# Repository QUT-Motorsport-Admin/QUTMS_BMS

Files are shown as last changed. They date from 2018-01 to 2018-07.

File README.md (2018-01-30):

QUTMS_Banner

# QUT Motorsport - Battery Management

### What
What is the system
### Why
Why is it there, whats its main purpose
### How
How dose it work, interact with other systems, whats its responding too, whats its enacting on
### Where
Where dose it sit in the grand scheme of things, whats its heirachy, where is it physicaly in the car
### Who
Who are the people that have worked on it over time

## Specific README's
These will cover any specific features, outlines or documentation that a programmer/designer should know about. Any specifics, or this outside the overview/outline please update an entry in the wiki

[Hardware](https://github.com/Technosasquach/QUTMS_BMS/tree/master/hardware "Hardware")

[Software](https://github.com/Technosasquach/QUTMS_BMS/tree/master/software "Software")

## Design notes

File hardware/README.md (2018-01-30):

# Battery Management System Hardware

Please update this as important hardware information comes to light

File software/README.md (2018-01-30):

# Battery Management System Software

The software for this project is in two parts. The controller system, and the accumulator system.

## AMU - Accumulator

A rough outline of the software process

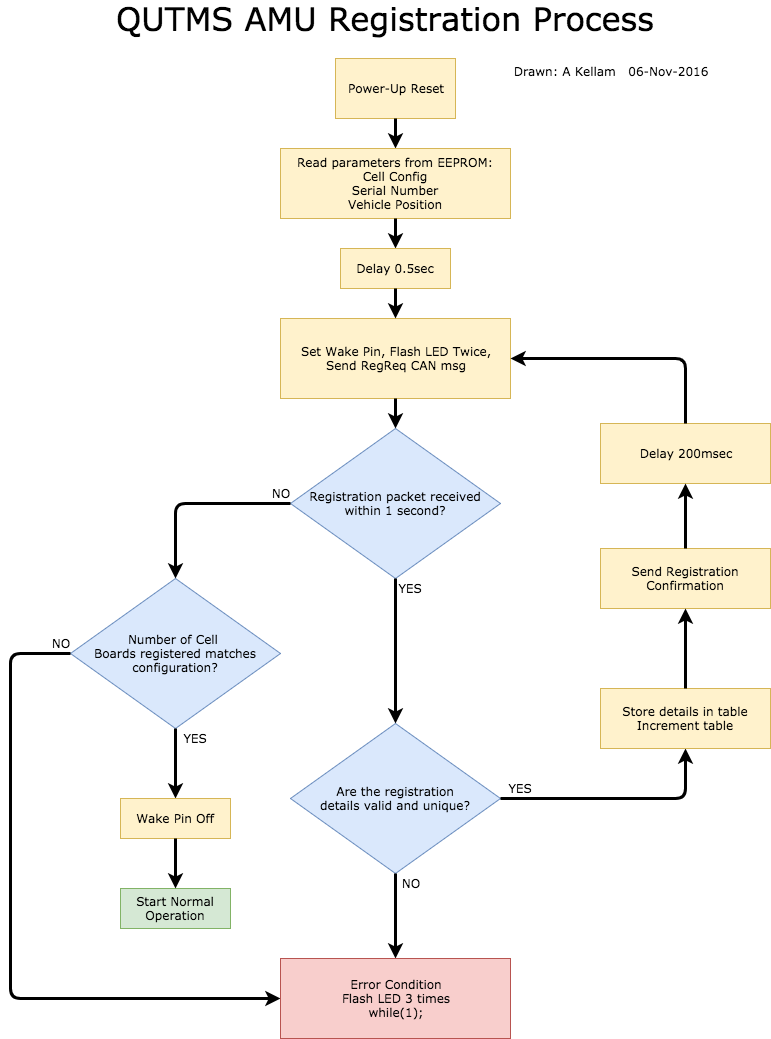
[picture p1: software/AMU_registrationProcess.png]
AccumulatorStartUpProcess


## CMU - Controller

A rough outline of the software process

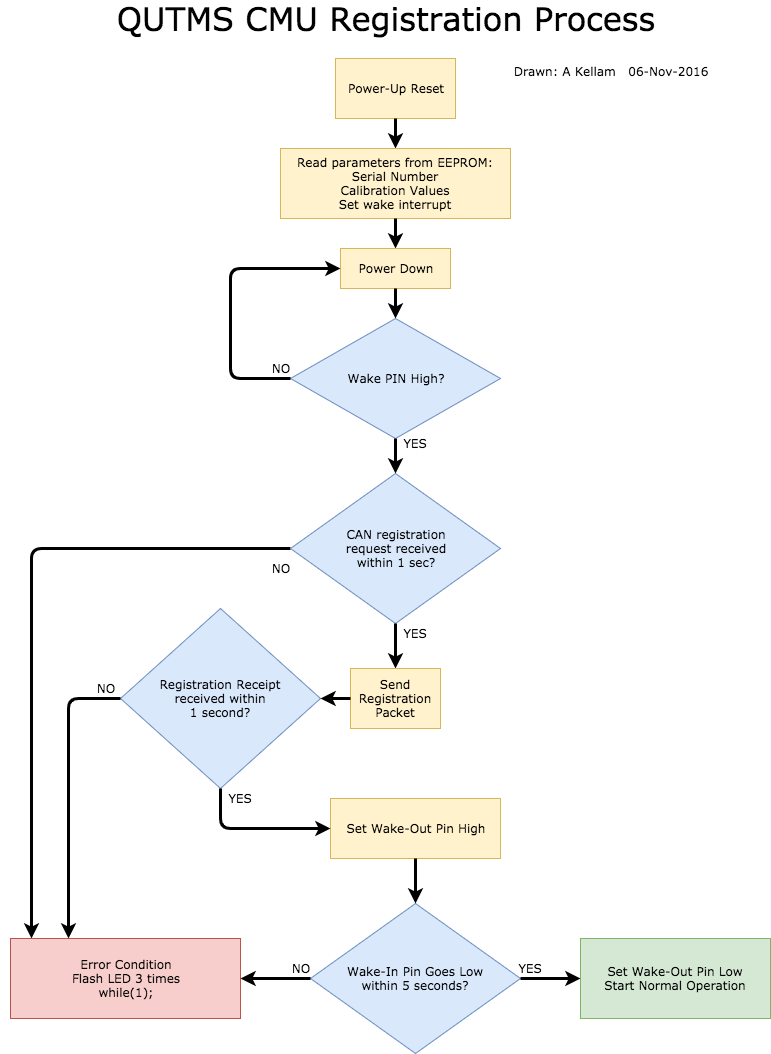
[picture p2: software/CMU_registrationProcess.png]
ControllerStartUpProcess


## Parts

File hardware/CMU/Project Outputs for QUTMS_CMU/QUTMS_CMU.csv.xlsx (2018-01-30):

Comment | Description | Designator | Footprint | LibRef | Supplier 1 | Pricing 1 | Pricing 2 | Quantity
100pF | 603 | C1, C2, C3, C4, C5, C6, C7, C8 | 1608[0603] | Cap Semi | Digi-Key | 1=0.14, 10=0.043, 25=0.0304, 50=0.0236, 100=0.0198, 500=0.01386, 1000=0.01079 (AUD) |  | 8
18pF | 603 | C9, C10 | 1608[0603] | Cap Semi |  |  |  | 2
1uF | 603 | C11, C38, C99 | 1608[0603] | Cap Semi |  |  |  | 3
100nF | 603 | C12, C14, C16, C17, C21, C22, C39, C40, C41, C50, C52 | 1608[0603] | Cap Semi | Digi-Key | 1=0.14, 10=0.028, 25=0.02, 50=0.0152, 100=0.0123, 250=0.01036, 500=0.00882, 1000=0.00693 (AUD) |  | 11
4.7uF | 603 | C13 | 1608[0603] | Cap Semi |  |  |  | 1
603 | 1uF, 47nF | C15, C20 | 1608[0603] | Cap Semi |  |  |  | 2
LED2 | Typical RED, GREEN, YELLOW, AMBER GaAs LED | D1 | 2012[0805]_Res | LED2 | Digi-Key | 1=0.54, 10=0.39, 25=0.2876, 100=0.2054, 250=0.13972, 500=0.12324, 1000=0.09655 (AUD) |  | 1
PWR | Typical RED, GREEN, YELLOW, AMBER GaAs LED | D2 | 2012[0805]_Res | LED2 | Digi-Key | 1=0.37, 10=0.274, 25=0.202, 100=0.1444, 250=0.09816, 500=0.08662, 1000=0.06785 (AUD) |  | 1
Fuse 1 | Fuse | F1, F2, F3, F4, F5, F6, F7, F8 | 3216[1206] | Fuse 1 | Digi-Key | 1=0.79, 50=0.5616, 100=0.5303, 250=0.49916, 500=0.46796 (AUD) |  | 8
Fuse 1 | Fuse | F9, F10, F11, F12, F13, F14, F15, F16 | 6426[2410]_Fuse | Fuse 1 | Digi-Key | 1=0.49, 10=0.458, 25=0.4224, 100=0.3796, 250=0.33808, 500=0.28172, 1000=0.26696, 2500=0.23879 (AUD) |  | 8
ISP header | Header, 3-Pin, Dual row | J1 | ISP Header | Header 3X2 | Digi-Key | 1=1.46, 10=1.283, 25=1.208, 50=1.1578, 100=1.1073 (AUD) |  | 1
Molex Connector | Header, 3-Pin, Dual row | J2 | MOLEX_6H_2 | Header 3X2A | Digi-Key | 1=4.47, 10=4.292, 25=3.934, 50=3.7552, 100=3.5761 (AUD) |  | 1
Molex Connector | Header, 3-Pin, Dual row | J3 | MOLEX_6H_1 | Header 3X2A | Digi-Key | 1=4.47, 10=4.292, 25=3.934, 50=3.7552, 100=3.5761 (AUD) |  | 1
10uH | 805 | L1 | 2012[0805]_IND | Inductor |  |  |  | 1
MOSFET-N | N-Channel MOSFET | Q1, Q2, Q3, Q4, Q5, Q6, Q7, Q8 | D2PAK_L | MOSFET-N | Digi-Key | 1=2.1, 10=1.888, 100=1.5146, 500=1.24488, 1000=1.03048 (AUD) | 1=0.8, 10=0.686, 100=0.5121, 500=0.4022, 1000=0.31009 (AUD) | 8
2N7002 | N-Channel MOSFET | Q9 | SOT23_N | MOSFET-N | Digi-Key | 1=0.19, 10=0.177, 100=0.0968, 500=0.05954, 1000=0.04061 (AUD) |  | 1
MOSFET-P | P-Channel MOSFET | Q10 | SOT23_N | MOSFET-P | Digi-Key | 1=0.5, 10=0.401, 25=0.3672, 100=0.2736, 250=0.24792, 500=0.20516, 1000=0.15387 (AUD) |  | 1
4R7 | Power Resistor SMD | R1, R2, R3, R4, R5, R6, R7, R8 | D2PAK_N | Res1 | Digi-Key | 1=3.71, 10=3.283, 25=3.0432, 50=2.8642, 100=2.5061, 250=2.14812, 500=1.7901, 1000=1.55142, 2500=1.52159 (AUD) |  | 8
1k | 805 | R9, R10, R11, R12, R13, R14, R15, R16, R60, R61, R63, R64, R65, R66, R69 | 2012[0805]_Res | Res1 |  |  |  | 15
560k | 805 | R17, R18, R19, R20, R21, R22, R23, R24, R25, R26, R27, R28, R29, R30, R31, R33, R34, R35, R36, R37, R38, R39, R40, R42, R43, R44, R45, R46, R47, R48 | 2012[0805]_Res | Res1 | Digi-Key | 1=0.14, 10=0.024, 25=0.0172, 100=0.0099, 250=0.00752, 500=0.006, 1000=0.00441, 2500=0.00383 (AUD) | 1=0.88, 50=0.3502, 100=0.2701, 250=0.21008, 500=0.14806, 1000=0.10804 (AUD) | 30
47k | 805 | R32, R41, R49, R50, R58, R59, R62, R83, R84, R85, R88, R97 | 2012[0805]_Res | Res1, Res1, Res1, Res1, Res1, Res1, Res1, Res1, Res1, Res1, Res3, Res1 | Digi-Key | 1=0.14, 50=0.021, 100=0.0154, 250=0.0118, 500=0.00946, 1000=0.00696 (AUD) |  | 12
10k | 805 | R51, R52, R53, R54, R55, R56, R57, R79, R80, R81, R82, R95a, R95b, R98 | 2012[0805]_Res | Res1 | Digi-Key | 1=0.14, 50=0.021, 100=0.0154, 250=0.0118, 500=0.00946, 1000=0.00696 (AUD) |  | 14
4k7 | 805 | R68, R70, R71, R72, R73, R74, R75, R76, R77 | 2012[0805]_Res | Res1, Res3, Res3, Res3, Res3, Res3, Res3, Res3, Res3 |  |  |  | 9
330R | 805 | R78 | 2012[0805]_Res | Res1 |  |  |  | 1
805 | 1k | R89 | 2012[0805]_Res | Res1 |  |  |  | 1
270R | 805 | R90, R91 | 2012[0805]_Res | Res1 |  |  |  | 2
22k | 805 | R96 | 2012[0805]_Res | Res1 |  |  |  | 1
10R | 805 | R99 | 2012[0805]_Res | Res1 |  |  |  | 1
Res Thermal | Thermistor | TH1, TH2, TH3, TH4, TH5, TH6, TH7, TH8 | HDR1X2 | Res Thermal |  |  |  | 8
ATmega64M1-16AU | 8-Bit AVR Microcontroller with 8K Bytes of In-System Programmable Flash Memory | U1 | 32A_N | ATmega8-16AC |  |  |  | 1
ISO1050 | Isolated CAN transceiver | U5 | DUB8 | AT90S2343-10SI | Digi-Key | 1=6.31, 10=5.665, 100=4.647 (AUD) |  | 1
MC33174D | Low-Power Quad Bipolar Operational Amplifier | U6, U7 | SO14_N | MC33174D | Digi-Key | 1=1.18, 10=1.036, 100=0.7921, 500=0.62762, 1000=0.5027 (AUD) |  | 2
Optoisolator1 | 4-Pin Phototransistor Optocoupler | U10, U11, U14, U15, U16, U17, U18, U19, U21 | SO4 | Optoisolator1 | Digi-Key | 1=1.12, 10=0.864, 25=0.718, 100=0.6172, 250=0.53864, 500=0.4713, 750=0.41521, 1000=0.37031 (AUD) |  | 9
Optoisolator3 | 4-Pin Phototransistor Optocoupler | U12 | SO4 | Optoisolator1 | Digi-Key | 1=1.12, 10=0.864, 25=0.718, 100=0.6172, 250=0.53864, 500=0.4713, 750=0.41521, 1000=0.37031 (AUD) |  | 1
Optoisolator4 | 4-Pin Phototransistor Optocoupler | U13 | SO4 | Optoisolator1 | Digi-Key | 1=1.12, 10=0.864, 25=0.718, 100=0.6172, 250=0.53864, 500=0.4713, 750=0.41521, 1000=0.37031 (AUD) |  | 1
74HC4051 | Wideband Dual-Channel Linear Multiplier/Divider | U20 | SO-16 | AD539KN | Digi-Key | 1=0.63, 10=0.51, 100=0.3475, 500=0.2601, 1000=0.19481 (AUD) |  | 1
5V LDO INH Reg | IC REG LDO 5V 0.4A TO252-5 | VR1 | DPAK-5 | IFX25401TE V50 | Digi-Key | 1=1.48, 10=1.325, 100=1.0328, 500=0.85324, 1000=0.6736 (AUD) |  | 1
MC78M05BDTRK | Three-Terminal Medium Current Positive Voltage Regulator | VR2 | D2PAK | MC78M05BDTRK | Digi-Key | 1=0.62, 10=0.531, 100=0.3968, 500=0.31168, 1000=0.24029 (AUD) |  | 1
16MHz | Crystal Oscillator | Y1 | Crystal | XTAL | Digi-Key | 1=0.32, 10=0.274, 50=0.2452, 100=0.2182, 500=0.2078 (AUD) |  | 1

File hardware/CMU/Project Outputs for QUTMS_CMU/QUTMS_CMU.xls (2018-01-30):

Comment | Description | Designator | Footprint | LibRef | Supplier 1 | Pricing 1 | Pricing 2 | Quantity
100pF | 0603 | C1, C2, C3, C4, C5, C6, C7, C8 | 1608[0603] | Cap Semi | Digi-Key | 1=0.14, 10=0.043, 25=0.0304, 50=0.0236, 100=0.0198, 500=0.01386, 1000=0.01079 (AUD) |  | 8.0
18pF | 0603 | C9, C10 | 1608[0603] | Cap Semi |  |  |  | 2.0
1uF | 0603 | C11, C38, C99 | 1608[0603] | Cap Semi |  |  |  | 3.0
100nF | 0603 | C12, C14, C16, C17, C21, C22, C39, C40, C41, C50, C52 | 1608[0603] | Cap Semi | Digi-Key | 1=0.14, 10=0.028, 25=0.02, 50=0.0152, 100=0.0123, 250=0.01036, 500=0.00882, 1000=0.00693 (AUD) |  | 11.0
4.7uF | 0603 | C13 | 1608[0603] | Cap Semi |  |  |  | 1.0
0603 | 1uF, 47nF | C15, C20 | 1608[0603] | Cap Semi |  |  |  | 2.0
LED2 | Typical RED, GREEN, YELLOW, AMBER GaAs LED | D1 | 2012[0805]_Res | LED2 | Digi-Key | 1=0.54, 10=0.39, 25=0.2876, 100=0.2054, 250=0.13972, 500=0.12324, 1000=0.09655 (AUD) |  | 1.0
PWR | Typical RED, GREEN, YELLOW, AMBER GaAs LED | D2 | 2012[0805]_Res | LED2 | Digi-Key | 1=0.37, 10=0.274, 25=0.202, 100=0.1444, 250=0.09816, 500=0.08662, 1000=0.06785 (AUD) |  | 1.0
Fuse 1 | Fuse | F1, F2, F3, F4, F5, F6, F7, F8 | 3216[1206] | Fuse 1 | Digi-Key | 1=0.79, 50=0.5616, 100=0.5303, 250=0.49916, 500=0.46796 (AUD) |  | 8.0
Fuse 1 | Fuse | F9, F10, F11, F12, F13, F14, F15, F16 | 6426[2410]_Fuse | Fuse 1 | Digi-Key | 1=0.49, 10=0.458, 25=0.4224, 100=0.3796, 250=0.33808, 500=0.28172, 1000=0.26696, 2500=0.23879 (AUD) |  | 8.0
ISP header | Header, 3-Pin, Dual row | J1 | ISP Header | Header 3X2 | Digi-Key | 1=1.46, 10=1.283, 25=1.208, 50=1.1578, 100=1.1073 (AUD) |  | 1.0
Molex Connector | Header, 3-Pin, Dual row | J2 | MOLEX_6H_2 | Header 3X2A | Digi-Key | 1=4.47, 10=4.292, 25=3.934, 50=3.7552, 100=3.5761 (AUD) |  | 1.0
Molex Connector | Header, 3-Pin, Dual row | J3 | MOLEX_6H_1 | Header 3X2A | Digi-Key | 1=4.47, 10=4.292, 25=3.934, 50=3.7552, 100=3.5761 (AUD) |  | 1.0
10uH | 0805 | L1 | 2012[0805]_IND | Inductor |  |  |  | 1.0
MOSFET-N | N-Channel MOSFET | Q1, Q2, Q3, Q4, Q5, Q6, Q7, Q8 | D2PAK_L | MOSFET-N | Digi-Key | 1=2.1, 10=1.888, 100=1.5146, 500=1.24488, 1000=1.03048 (AUD) | 1=0.8, 10=0.686, 100=0.5121, 500=0.4022, 1000=0.31009 (AUD) | 8.0
2N7002 | N-Channel MOSFET | Q9 | SOT23_N | MOSFET-N | Digi-Key | 1=0.19, 10=0.177, 100=0.0968, 500=0.05954, 1000=0.04061 (AUD) |  | 1.0
MOSFET-P | P-Channel MOSFET | Q10 | SOT23_N | MOSFET-P | Digi-Key | 1=0.5, 10=0.401, 25=0.3672, 100=0.2736, 250=0.24792, 500=0.20516, 1000=0.15387 (AUD) |  | 1.0
4R7 | Power Resistor SMD | R1, R2, R3, R4, R5, R6, R7, R8 | D2PAK_N | Res1 | Digi-Key | 1=3.71, 10=3.283, 25=3.0432, 50=2.8642, 100=2.5061, 250=2.14812, 500=1.7901, 1000=1.55142, 2500=1.52159 (AUD) |  | 8.0
1k | 0805 | R9, R10, R11, R12, R13, R14, R15, R16, R60, R61, R63, R64, R65, R66, R69 | 2012[0805]_Res | Res1 |  |  |  | 15.0
560k | 0805 | R17, R18, R19, R20, R21, R22, R23, R24, R25, R26, R27, R28, R29, R30, R31, R33, R34, R35, R36, R37, R38, R39, R40, R42, R43, R44, R45, R46, R47, R48 | 2012[0805]_Res | Res1 | Digi-Key | 1=0.14, 10=0.024, 25=0.0172, 100=0.0099, 250=0.00752, 500=0.006, 1000=0.00441, 2500=0.00383 (AUD) | 1=0.88, 50=0.3502, 100=0.2701, 250=0.21008, 500=0.14806, 1000=0.10804 (AUD) | 30.0
47k | 0805 | R32, R41, R49, R50, R58, R59, R62, R83, R84, R85, R88, R97 | 2012[0805]_Res | Res1, Res1, Res1, Res1, Res1, Res1, Res1, Res1, Res1, Res1, Res3, Res1 | Digi-Key | 1=0.14, 50=0.021, 100=0.0154, 250=0.0118, 500=0.00946, 1000=0.00696 (AUD) |  | 12.0
10k | 0805 | R51, R52, R53, R54, R55, R56, R57, R79, R80, R81, R82, R95a, R95b, R98 | 2012[0805]_Res | Res1 | Digi-Key | 1=0.14, 50=0.021, 100=0.0154, 250=0.0118, 500=0.00946, 1000=0.00696 (AUD) |  | 14.0
4k7 | 0805 | R68, R70, R71, R72, R73, R74, R75, R76, R77 | 2012[0805]_Res | Res1, Res3, Res3, Res3, Res3, Res3, Res3, Res3, Res3 |  |  |  | 9.0
330R | 0805 | R78 | 2012[0805]_Res | Res1 |  |  |  | 1.0
0805 | 1k | R89 | 2012[0805]_Res | Res1 |  |  |  | 1.0
270R | 0805 | R90, R91 | 2012[0805]_Res | Res1 |  |  |  | 2.0
22k | 0805 | R96 | 2012[0805]_Res | Res1 |  |  |  | 1.0
10R | 0805 | R99 | 2012[0805]_Res | Res1 |  |  |  | 1.0
Res Thermal | Thermistor | TH1, TH2, TH3, TH4, TH5, TH6, TH7, TH8 | HDR1X2 | Res Thermal |  |  |  | 8.0
ATmega64M1-16AU | 8-Bit AVR Microcontroller with 8K Bytes of In-System Programmable Flash Memory | U1 | 32A_N | ATmega8-16AC |  |  |  | 1.0
ISO1050 | Isolated CAN transceiver | U5 | DUB8 | AT90S2343-10SI | Digi-Key | 1=6.31, 10=5.665, 100=4.647 (AUD) |  | 1.0
MC33174D | Low-Power Quad Bipolar Operational Amplifier | U6, U7 | SO14_N | MC33174D | Digi-Key | 1=1.18, 10=1.036, 100=0.7921, 500=0.62762, 1000=0.5027 (AUD) |  | 2.0
Optoisolator1 | 4-Pin Phototransistor Optocoupler | U10, U11, U14, U15, U16, U17, U18, U19, U21 | SO4 | Optoisolator1 | Digi-Key | 1=1.12, 10=0.864, 25=0.718, 100=0.6172, 250=0.53864, 500=0.4713, 750=0.41521, 1000=0.37031 (AUD) |  | 9.0
Optoisolator3 | 4-Pin Phototransistor Optocoupler | U12 | SO4 | Optoisolator1 | Digi-Key | 1=1.12, 10=0.864, 25=0.718, 100=0.6172, 250=0.53864, 500=0.4713, 750=0.41521, 1000=0.37031 (AUD) |  | 1.0
Optoisolator4 | 4-Pin Phototransistor Optocoupler | U13 | SO4 | Optoisolator1 | Digi-Key | 1=1.12, 10=0.864, 25=0.718, 100=0.6172, 250=0.53864, 500=0.4713, 750=0.41521, 1000=0.37031 (AUD) |  | 1.0
74HC4051 | Wideband Dual-Channel Linear Multiplier/Divider | U20 | SO-16 | AD539KN | Digi-Key | 1=0.63, 10=0.51, 100=0.3475, 500=0.2601, 1000=0.19481 (AUD) |  | 1.0
5V LDO INH Reg | IC REG LDO 5V 0.4A TO252-5 | VR1 | DPAK-5 | IFX25401TE V50 | Digi-Key | 1=1.48, 10=1.325, 100=1.0328, 500=0.85324, 1000=0.6736 (AUD) |  | 1.0
MC78M05BDTRK | Three-Terminal Medium Current Positive Voltage Regulator | VR2 | D2PAK | MC78M05BDTRK | Digi-Key | 1=0.62, 10=0.531, 100=0.3968, 500=0.31168, 1000=0.24029 (AUD) |  | 1.0
16MHz | Crystal Oscillator | Y1 | Crystal | XTAL | Digi-Key | 1=0.32, 10=0.274, 50=0.2452, 100=0.2182, 500=0.2078 (AUD) |  | 1.0

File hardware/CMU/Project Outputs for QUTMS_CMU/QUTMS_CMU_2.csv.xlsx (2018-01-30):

Comment | Description | Designator | Footprint | LibRef | Supplier 1 | Pricing 1 | Pricing 2 | Quantity | Manufacturer | Manufacturer Part Number | ComponentLink1URL | ComponentLink2URL | ComponentLink3URL
100pF | 603 | C1, C2, C3, C4, C5, C6, C7, C8 | 1608[0603] | Cap Semi | Digi-Key | 1=0.14, 10=0.043, 25=0.0304, 50=0.0236, 100=0.0198, 500=0.01386, 1000=0.01079 (AUD) |  | 8 | Samsung Electro-Mechanics America, Inc. | CL10B101KB8NNNC | http://www.samsungsem.com/kr/support/product-search/mlcc/CL10B101KB8NNNC.jsp
18pF | 603 | C9, C10 | 1608[0603] | Cap Semi |  |  |  | 2
1uF | 603 | C11, C38, C99 | 1608[0603] | Cap Semi |  |  |  | 3
100nF | 603 | C12, C14, C16, C17, C21, C22, C39, C40, C41, C50, C52 | 1608[0603] | Cap Semi | Digi-Key | 1=0.14, 10=0.028, 25=0.02, 50=0.0152, 100=0.0123, 250=0.01036, 500=0.00882, 1000=0.00693 (AUD) |  | 11 | Samsung Electro-Mechanics America, Inc. | CL10B104KB8SFNC | http://www.samsungsem.com/kr/support/product-search/mlcc/CL10B104KB8SFNC.jsp
4.7uF | 603 | C13 | 1608[0603] | Cap Semi |  |  |  | 1
603 | 1uF, 47nF | C15, C20 | 1608[0603] | Cap Semi |  |  |  | 2
LED2 | Typical RED, GREEN, YELLOW, AMBER GaAs LED | D1 | 2012[0805]_Res | LED2 | Digi-Key | 1=0.54, 10=0.39, 25=0.2876, 100=0.2054, 250=0.13972, 500=0.12324, 1000=0.09655 (AUD) |  | 1 | Kingbright | APT2012SGC | http://www.kingbrightusa.com/images/catalog/SPEC/APT2012SGC.pdf
PWR | Typical RED, GREEN, YELLOW, AMBER GaAs LED | D2 | 2012[0805]_Res | LED2 | Digi-Key | 1=0.37, 10=0.274, 25=0.202, 100=0.1444, 250=0.09816, 500=0.08662, 1000=0.06785 (AUD) |  | 1 | OSRAM Opto Semiconductors Inc. | LS R976-NR-1 | http://www.osram-os.com/Graphics/XPic8/00078896_0.pdf
Fuse 1 | Fuse | F1, F2, F3, F4, F5, F6, F7, F8 | 3216[1206] | Fuse 1 | Digi-Key | 1=0.79, 50=0.5616, 100=0.5303, 250=0.49916, 500=0.46796 (AUD) |  | 8 | Schurter Inc. | 3413.0008.22 | http://www.schurterinc.com/bundles/snceschurter/epim/_ProdPool_/newDS/en/typ_USFF_1206.pdf
Fuse 1 | Fuse | F9, F10, F11, F12, F13, F14, F15, F16 | 6426[2410]_Fuse | Fuse 1 | Digi-Key | 1=0.49, 10=0.458, 25=0.4224, 100=0.3796, 250=0.33808, 500=0.28172, 1000=0.26696, 2500=0.23879 (AUD) |  | 8 | Bel Fuse Inc. | 0679L5000-05 | http://belfuse.com/pdfs/0679L.pdf
ISP header | Header, 3-Pin, Dual row | J1 | ISP Header | Header 3X2 | Digi-Key | 1=1.46, 10=1.283, 25=1.208, 50=1.1578, 100=1.1073 (AUD) |  | 1 | Amphenol FCI | 95278-101A06LF | http://portal.fciconnect.com/Comergent//fci/drawing/95278.pdf
Molex Connector | Header, 3-Pin, Dual row | J2 | MOLEX_6H_2 | Header 3X2A | Digi-Key | 1=4.47, 10=4.292, 25=3.934, 50=3.7552, 100=3.5761 (AUD) |  | 1 | Molex, LLC | 430450610 | http://www.molex.com/pdm_docs/sd/430450610_sd.pdf
Molex Connector | Header, 3-Pin, Dual row | J3 | MOLEX_6H_1 | Header 3X2A | Digi-Key | 1=4.47, 10=4.292, 25=3.934, 50=3.7552, 100=3.5761 (AUD) |  | 1 | Molex, LLC | 430450610 | http://www.molex.com/pdm_docs/sd/430450610_sd.pdf
10uH | 805 | L1 | 2012[0805]_IND | Inductor |  |  |  | 1
MOSFET-N | N-Channel MOSFET | Q1, Q2, Q3, Q4, Q5, Q6, Q7, Q8 | D2PAK_L | MOSFET-N | Digi-Key | 1=2.1, 10=1.888, 100=1.5146, 500=1.24488, 1000=1.03048 (AUD) | 1=0.8, 10=0.686, 100=0.5121, 500=0.4022, 1000=0.31009 (AUD) | 8 | Fairchild Semiconductor | FDD86250 | http://www.fairchildsemi.com/datasheets/FD/FDD86250.pdf | http://www.onsemi.com/pub_link/Collateral/MJD122-D.PDF
2N7002 | N-Channel MOSFET | Q9 | SOT23_N | MOSFET-N | Digi-Key | 1=0.19, 10=0.177, 100=0.0968, 500=0.05954, 1000=0.04061 (AUD) |  | 1 | NXP Semiconductors | 2N7002P,215 | http://www.nxp.com/documents/data_sheet/2N7002P.pdf
MOSFET-P | P-Channel MOSFET | Q10 | SOT23_N | MOSFET-P | Digi-Key | 1=0.5, 10=0.401, 25=0.3672, 100=0.2736, 250=0.24792, 500=0.20516, 1000=0.15387 (AUD) |  | 1 | Vishay Siliconix | TP0610K-T1-GE3 | http://www.vishay.com/docs/71411/tp0610k.pdf
4R7 | Power Resistor SMD | R1, R2, R3, R4, R5, R6, R7, R8 | D2PAK_N | Res1 | Digi-Key | 1=3.71, 10=3.283, 25=3.0432, 50=2.8642, 100=2.5061, 250=2.14812, 500=1.7901, 1000=1.55142, 2500=1.52159 (AUD) | 1=3.65, 10=3.234, 25=2.9984, 50=2.8218, 100=2.469, 250=2.11628, 500=1.76358, 1000=1.52844, 2500=1.49904 (AUD) | 8 | Bourns Inc. | PWR163S-25-1R00J | http://www.bourns.com/docs/Product-Datasheets/PWR163.pdf
1k | 805 | R9, R10, R11, R12, R13, R14, R15, R16, R60, R61, R63, R64, R65, R66, R69 | 2012[0805]_Res | Res1 |  |  |  | 15
560k | 805 | R17, R18, R19, R20, R21, R22, R23, R24, R25, R26, R27, R28, R29, R30, R31, R33, R34, R35, R36, R37, R38, R39, R40, R42, R43, R44, R45, R46, R47, R48 | 2012[0805]_Res | Res1 | Digi-Key | 1=0.14, 10=0.024, 25=0.0172, 100=0.0099, 250=0.00752, 500=0.006, 1000=0.00441, 2500=0.00383 (AUD) | 1=0.88, 50=0.3502, 100=0.2701, 250=0.21008, 500=0.14806, 1000=0.10804 (AUD) | 30 | Yageo | RC0805JR-07560KL | http://www.yageo.com/documents/recent/PYu-RC_Group_51_RoHS_L_04.pdf | http://media.digikey.com/pdf/Data%20Sheets/Panasonic%20Electronic%20Components/ERA%201A,2A,3A,6A,8A.pdf
47k | 805 | R32, R41, R49, R50, R58, R59, R62, R83, R84, R85, R88, R97 | 2012[0805]_Res | Res1, Res1, Res1, Res1, Res1, Res1, Res1, Res1, Res1, Res1, Res3, Res1 | Digi-Key | 1=0.14, 50=0.021, 100=0.0154, 250=0.0118, 500=0.00946, 1000=0.00696 (AUD) |  | 12 | Panasonic Electronic Components | ERJ-6GEYJ473V | http://industrial.panasonic.com/www-cgi/jvcr13pz.cgi?E+PZ+3+AOA0001+ERJ6GEYJ473V+7+WW
10k | 805 | R51, R52, R53, R54, R55, R56, R57, R79, R80, R81, R82, R95a, R95b, R98 | 2012[0805]_Res | Res1 | Digi-Key | 1=0.14, 50=0.021, 100=0.0154, 250=0.0118, 500=0.00946, 1000=0.00696 (AUD) |  | 14 | Panasonic Electronic Components | ERJ-6GEYJ103V | http://industrial.panasonic.com/www-cgi/jvcr13pz.cgi?E+PZ+3+AOA0001+ERJ6GEYJ103V+7+WW
4k7 | 805 | R68, R70, R71, R72, R73, R74, R75, R76, R77 | 2012[0805]_Res | Res1, Res3, Res3, Res3, Res3, Res3, Res3, Res3, Res3 |  |  |  | 9
330R | 805 | R78 | 2012[0805]_Res | Res1 |  |  |  | 1
805 | 1k | R89 | 2012[0805]_Res | Res1 |  |  |  | 1
270R | 805 | R90, R91 | 2012[0805]_Res | Res1 |  |  |  | 2
22k | 805 | R96 | 2012[0805]_Res | Res1 |  |  |  | 1
10R | 805 | R99 | 2012[0805]_Res | Res1 |  |  |  | 1
Res Thermal | Thermistor | TH1, TH2, TH3, TH4, TH5, TH6, TH7, TH8 | HDR1X2 | Res Thermal |  |  |  | 8
ATmega64M1-16AU | 8-Bit AVR Microcontroller with 8K Bytes of In-System Programmable Flash Memory | U1 | 32A_N | ATmega8-16AC |  |  |  | 1 |  |  | http://www.atmel.com | http://www.atmel.com/dyn/resources/prod_documents/doc2486.pdf
ISO1050 | Isolated CAN transceiver | U5 | DUB8 | AT90S2343-10SI | Digi-Key | 1=6.31, 10=5.665, 100=4.647 (AUD) |  | 1 | Texas Instruments | ISO1050DUBR | http://www.atmel.com | http://www.atmel.com/dyn/resources/prod_documents/doc1004.pdf | http://www.ti.com/lit/ds/symlink/iso1050.pdf
MC33174D | Low-Power Quad Bipolar Operational Amplifier | U6, U7 | SO14_N | MC33174D | Digi-Key | 1=1.18, 10=1.036, 100=0.7921, 500=0.62762, 1000=0.5027 (AUD) |  | 2 | STMicroelectronics | MC33174DT | http://www.st.com/ | http://www.st.com/stonline/products/literature/ds/2180/mc33174.pdf | http://www.st.com/content/ccc/resource/technical/document/datasheet/2e/90/c8/0c/79/aa/43/e1/CD00000477.pdf/files/CD00000477.pdf/jcr:content/translations/en.CD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
Optoisolator1 | 4-Pin Phototransistor Optocoupler | U10, U11, U14, U15, U16, U17, U18, U19, U21 | SO4 | Optoisolator1 | Digi-Key | 1=1.12, 10=0.864, 25=0.718, 100=0.6172, 250=0.53864, 500=0.4713, 750=0.41521, 1000=0.37031 (AUD) |  | 9 | Vishay Semiconductor Opto Division | TCMT1600 | http://www.vishay.com/docs/83512/tcmt1600.pdf
Optoisolator3 | 4-Pin Phototransistor Optocoupler | U12 | SO4 | Optoisolator1 | Digi-Key | 1=1.12, 10=0.864, 25=0.718, 100=0.6172, 250=0.53864, 500=0.4713, 750=0.41521, 1000=0.37031 (AUD) |  | 1 | Vishay Semiconductor Opto Division | TCMT1600 | http://www.vishay.com/docs/83512/tcmt1600.pdf
Optoisolator4 | 4-Pin Phototransistor Optocoupler | U13 | SO4 | Optoisolator1 | Digi-Key | 1=1.12, 10=0.864, 25=0.718, 100=0.6172, 250=0.53864, 500=0.4713, 750=0.41521, 1000=0.37031 (AUD) |  | 1 | Vishay Semiconductor Opto Division | TCMT1600 | http://www.vishay.com/docs/83512/tcmt1600.pdf
74HC4051 | Wideband Dual-Channel Linear Multiplier/Divider | U20 | SO-16 | AD539KN | Digi-Key | 1=0.63, 10=0.51, 100=0.3475, 500=0.2601, 1000=0.19481 (AUD) |  | 1 | NXP Semiconductors | 74HC4051D,653 | http://www.analog.com/en/prod/0%2C2877%2CAD539%2C00.html | http://www.analog.com/UploadedFiles/Data_Sheets/533994331AD539_a.pdf | http://www.nxp.com/documents/data_sheet/74HC_HCT4051.pdf
5V LDO INH Reg | IC REG LDO 5V 0.4A TO252-5 | VR1 | DPAK-5 | IFX25401TE V50 | Digi-Key | 1=1.48, 10=1.325, 100=1.0328, 500=0.85324, 1000=0.6736 (AUD) |  | 1 | Infineon Technologies | IFX25401TE V50 | http://www.infineon.com/dgdl/Infineon-IFX25401-DS-v01_02-en.pdf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
MC78M05BDTRK | Three-Terminal Medium Current Positive Voltage Regulator | VR2 | D2PAK | MC78M05BDTRK | Digi-Key | 1=0.62, 10=0.531, 100=0.3968, 500=0.31168, 1000=0.24029 (AUD) |  | 1 | ON Semiconductor | MC78M05CDTRKG | http://www.onsemi.com/site/products/taxonomy/0,4438,503,00.html | http://www.onsemi.com/pub/Collateral/MC78M00-D.PDF | http://www.onsemi.com/pub_link/Collateral/MC78M00-D.PDF
16MHz | Crystal Oscillator | Y1 | Crystal | XTAL | Digi-Key | 1=0.32, 10=0.274, 50=0.2452, 100=0.2182, 500=0.2078 (AUD) |  | 1 | Abracon LLC | ABLS-16.000MHZ-D-4-T | http://www.abracon.com/Resonators/abls.pdf

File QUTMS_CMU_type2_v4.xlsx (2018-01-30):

Comment | Description | Designator | Footprint | LibRef | Quantity
100pF | 0603 | C1, C2, C3, C4, C5, C6, C7, C8 | 1608[0603] | Cap Semi | 8
18pF | 0603 | C9, C10 | 1608[0603] | Cap Semi | 2
1uF | 0603 | C11, C38, C99 | 1608[0603] | Cap Semi | 3
100nF | 0603 | C12, C14, C16, C17, C21, C22, C39, C40, C41, C50, C52 | 1608[0603] | Cap Semi | 11
4.7uF | 0603 | C13 | 1608[0603] | Cap Semi | 1
0603 | 1uF, 47nF | C15, C20 | 1608[0603] | Cap Semi | 2
LED2 | Typical RED, GREEN, YELLOW, AMBER GaAs LED | D1 | 2012[0805]_RES | LED2 | 1
PWR | Typical RED, GREEN, YELLOW, AMBER GaAs LED | D2 | 2012[0805]_RES | LED2 | 1
Fuse 1 | Fuse | F1, F2, F3, F4, F5, F6, F7, F8 | 3216[1206] | Fuse 1 | 8
Fuse 1 | Fuse | F9, F10, F11, F12, F13, F14, F15, F16 | 6426[2410]_Fuse | Fuse 1 | 8
ISP header | Header, 3-Pin, Dual row | J1 | ISP HEADER | Header 3X2 | 1
Molex Connector | Header, 3-Pin, Dual row | J2 | MOLEX_6H_2 | Header 3X2A | 1
Molex Connector | Header, 3-Pin, Dual row | J3 | MOLEX_6H_1 | Header 3X2A | 1
10uH | 0805 | L1 | 2012[0805]_IND | Inductor | 1
 |  | Q1, Q2, Q3, Q4, Q5, Q6, Q7, Q8 | 369A-13 |  | 8
2N7002 | N-Channel MOSFET | Q9 | SOT23_N | MOSFET-N | 1
MOSFET-P | P-Channel MOSFET | Q10 | SOT23_N | MOSFET-P | 1
4R7 | Power Resistor SMD | R1, R2, R3, R4, R5, R6, R7, R8 | D2PAK_N | Res1 | 8
1k | 0805 | R9, R10, R11, R12, R13, R14, R15, R16, R60, R61, R63, R64, R65, R66, R69 | 2012[0805]_RES | Res1 | 15
560k | 0805 | R17, R18, R19, R20, R21, R22, R23, R24, R25, R26, R27, R28, R29, R30, R31, R33, R34, R35, R36, R37, R38, R39, R40, R42, R43, R44, R45, R46, R47, R48 | 2012[0805]_RES | Res1 | 30
47k | 0805 | R32, R41, R49, R50, R58, R59, R62, R83, R84, R85, R88, R97 | 2012[0805]_RES | Res1, Res1, Res1, Res1, Res1, Res1, Res1, Res1, Res1, Res1, Res3, Res1 | 12
10k | 0805 | R51, R52, R53, R54, R55, R56, R57, R79, R80, R81, R82, R95a, R95b, R98 | 2012[0805]_RES | Res1 | 14
4k7 | 0805 | R68, R70, R71, R72, R73, R74, R75, R76, R77 | 2012[0805]_RES | Res1, Res3, Res3, Res3, Res3, Res3, Res3, Res3, Res3 | 9
330R | 0805 | R78 | 2012[0805]_RES | Res1 | 1
0805 | 1k | R89 | 2012[0805]_RES | Res1 | 1
270R | 0805 | R90, R91 | 2012[0805]_RES | Res1 | 2
22k | 0805 | R96 | 2012[0805]_RES | Res1 | 1
10R | 0805 | R99 | 2012[0805]_RES | Res1 | 1
Res Thermal | Thermistor | TH1, TH2, TH3, TH4, TH5, TH6, TH7, TH8 | HDR1X2 | Res Thermal | 8
ATmega64M1-16AU | 8-Bit AVR Microcontroller with 8K Bytes of In-System Programmable Flash Memory | U1 | 32A_N | ATmega8-16AC | 1
ISO1050 | Isolated CAN transceiver | U5 | DUB8 | AT90S2343-10SI | 1
MC33174D | Low-Power Quad Bipolar Operational Amplifier | U6, U7 | SO14_N | MC33174D | 2
Optoisolator1 | 4-Pin Phototransistor Optocoupler | U10, U11, U14, U15, U16, U17, U18, U19, U21 | SO4 | Optoisolator1 | 9
Optoisolator3 | 4-Pin Phototransistor Optocoupler | U12 | SO4 | Optoisolator1 | 1
Optoisolator4 | 4-Pin Phototransistor Optocoupler | U13 | SO4 | Optoisolator1 | 1
74HC4051 | Wideband Dual-Channel Linear Multiplier/Divider | U20 | SO-16 | AD539KN | 1
5V LDO INH Reg | IC REG LDO 5V 0.4A TO252-5 | VR1 | DPAK-5 | IFX25401TE V50 | 1
MC78M05BDTRK | Three-Terminal Medium Current Positive Voltage Regulator | VR2 | D2PAK | MC78M05BDTRK | 1
16MHz | Crystal Oscillator | Y1 | CRYSTAL | XTAL | 1

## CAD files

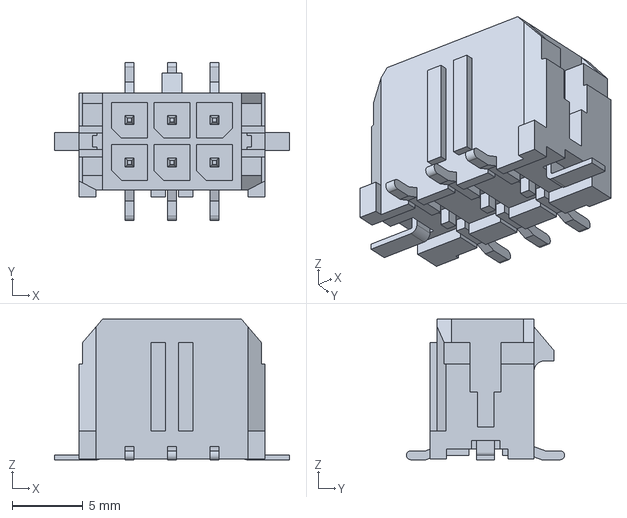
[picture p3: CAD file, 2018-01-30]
hardware/AMU/3D Models/Components/430450618.stp
16.6 x 11.2 x 9.96 mm

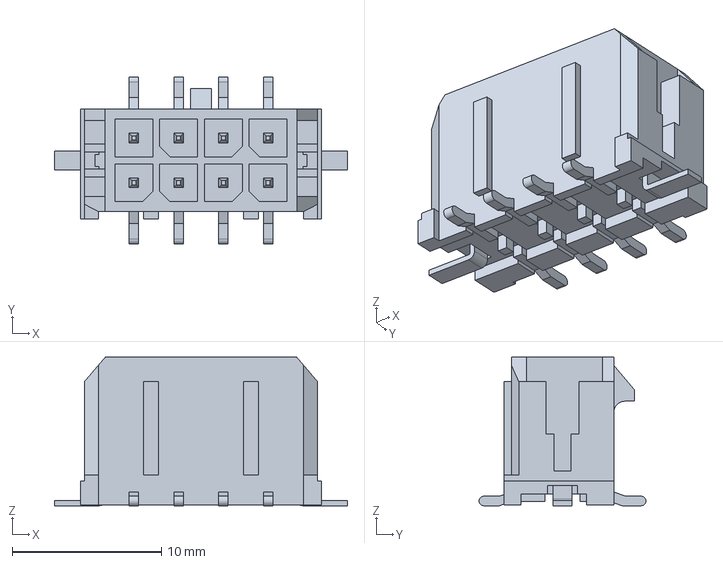
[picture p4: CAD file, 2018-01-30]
hardware/AMU/3D Models/Components/430450818.stp
19.6 x 11.2 x 9.96 mm

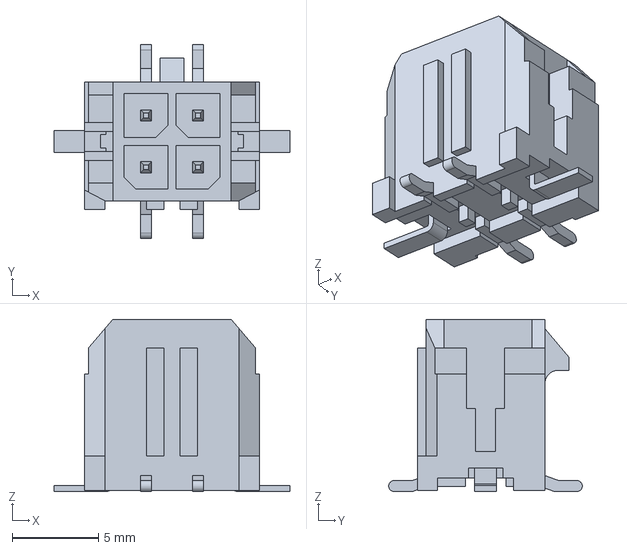
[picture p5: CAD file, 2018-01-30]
hardware/AMU/3D Models/Components/430450419.stp
13.7 x 11.2 x 9.96 mm

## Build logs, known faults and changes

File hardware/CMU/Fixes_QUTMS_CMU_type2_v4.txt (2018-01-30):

R90 needs to be 1k instead of 270R.
Need a 10uF capacitor on the output of the reg. maybe 2 10uF and a 100nF, or a 10uF, 4.7 uF, 100nF.

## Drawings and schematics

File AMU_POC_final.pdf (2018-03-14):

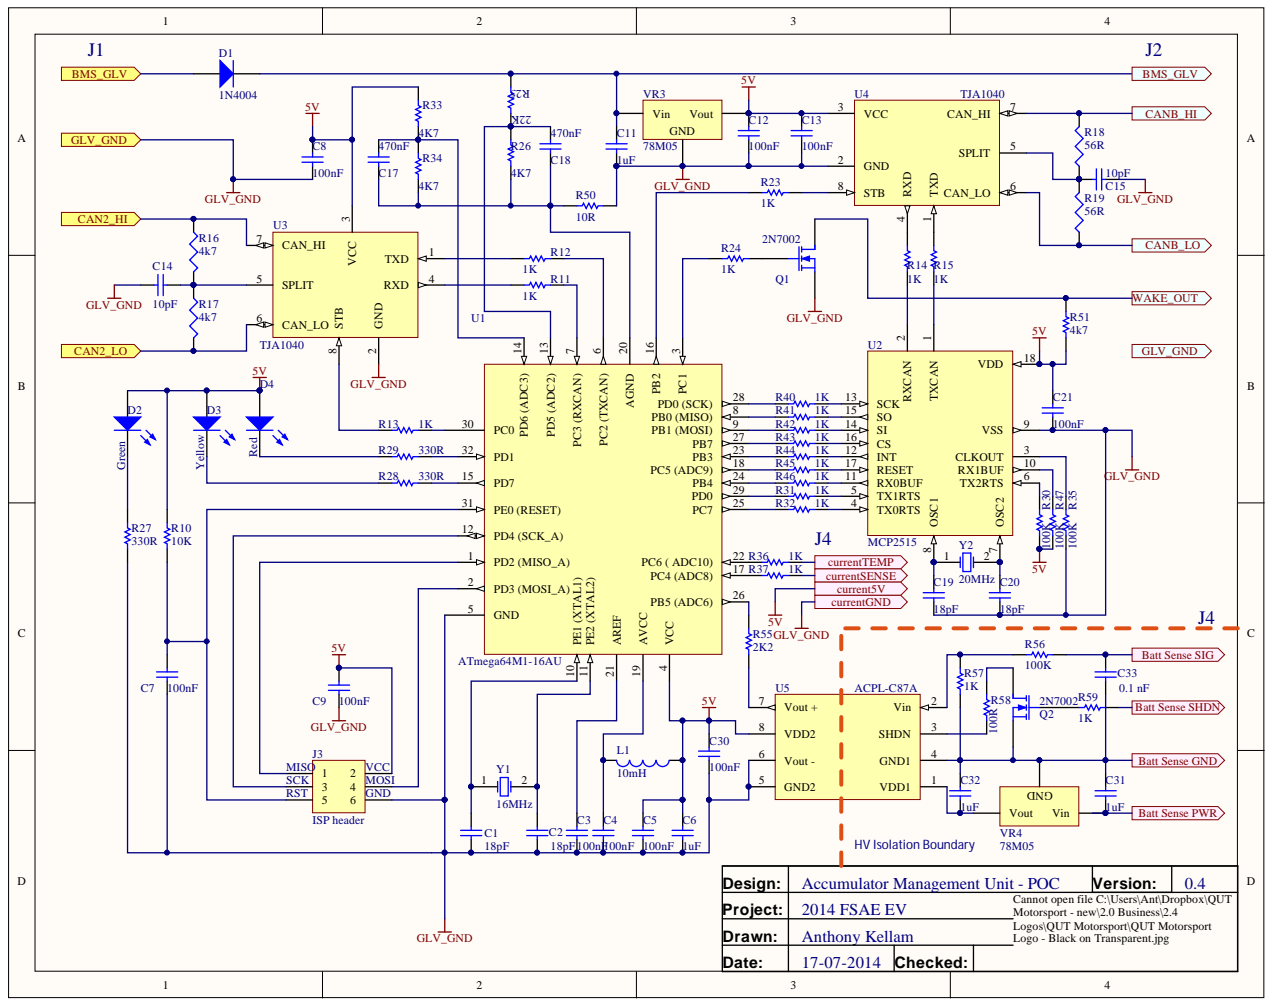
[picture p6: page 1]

CAN_HI 7 | RXD | 4 SPLIT 5

PD4 (SCK_A) 12

PD3 (MOSI_A) 2 | C19

GND 5

R56 | Batt Sense SIG 2K2

Vout + 7 | SHDN

VDD2 8 | | 3

Vout - 6

100nF | | GND2 5

16MHz | HV Isolation Boundary | 1uF

Design: | Accumulator Management Unit - POC | Version: | 0.4
Project: | Cannot open file C:\Users\Ant\Dropbox\QUT 2014 FSAE EV Motorsport - new\2.0 Business\2.4 Logos\QUT Motorsport\QUT Motorsport Logo - Black on Transparent.jpg

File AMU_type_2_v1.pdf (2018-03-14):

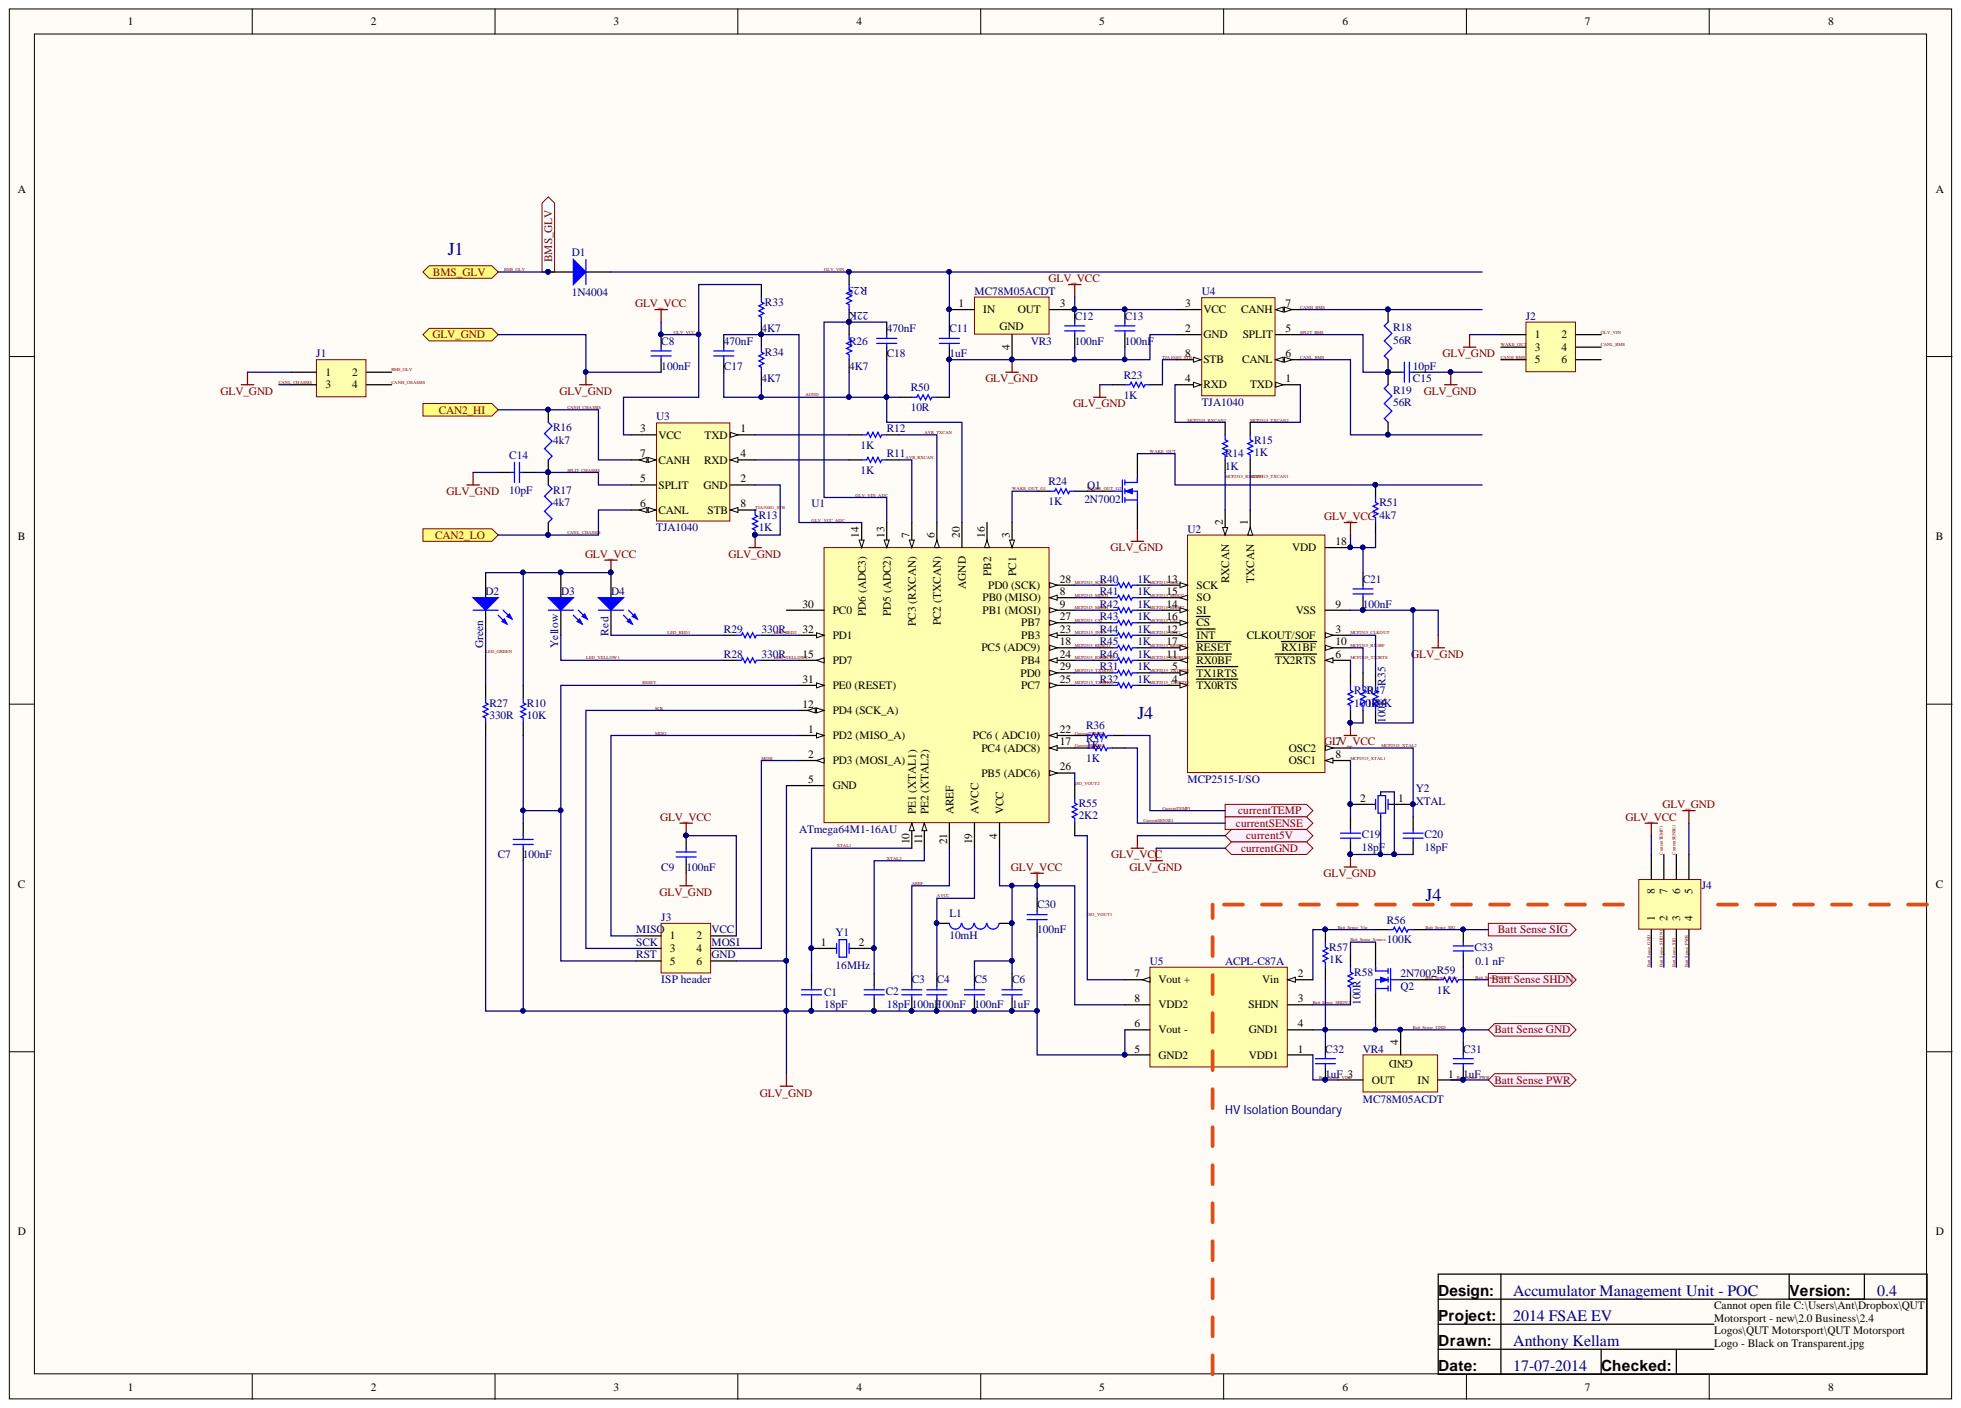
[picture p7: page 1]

PD4 (SCK_A) 12

PD2 (MISO_A) 1

PD3 (MOSI_A) 2

GND 5

Vout - 6

GND2 5 | C32

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

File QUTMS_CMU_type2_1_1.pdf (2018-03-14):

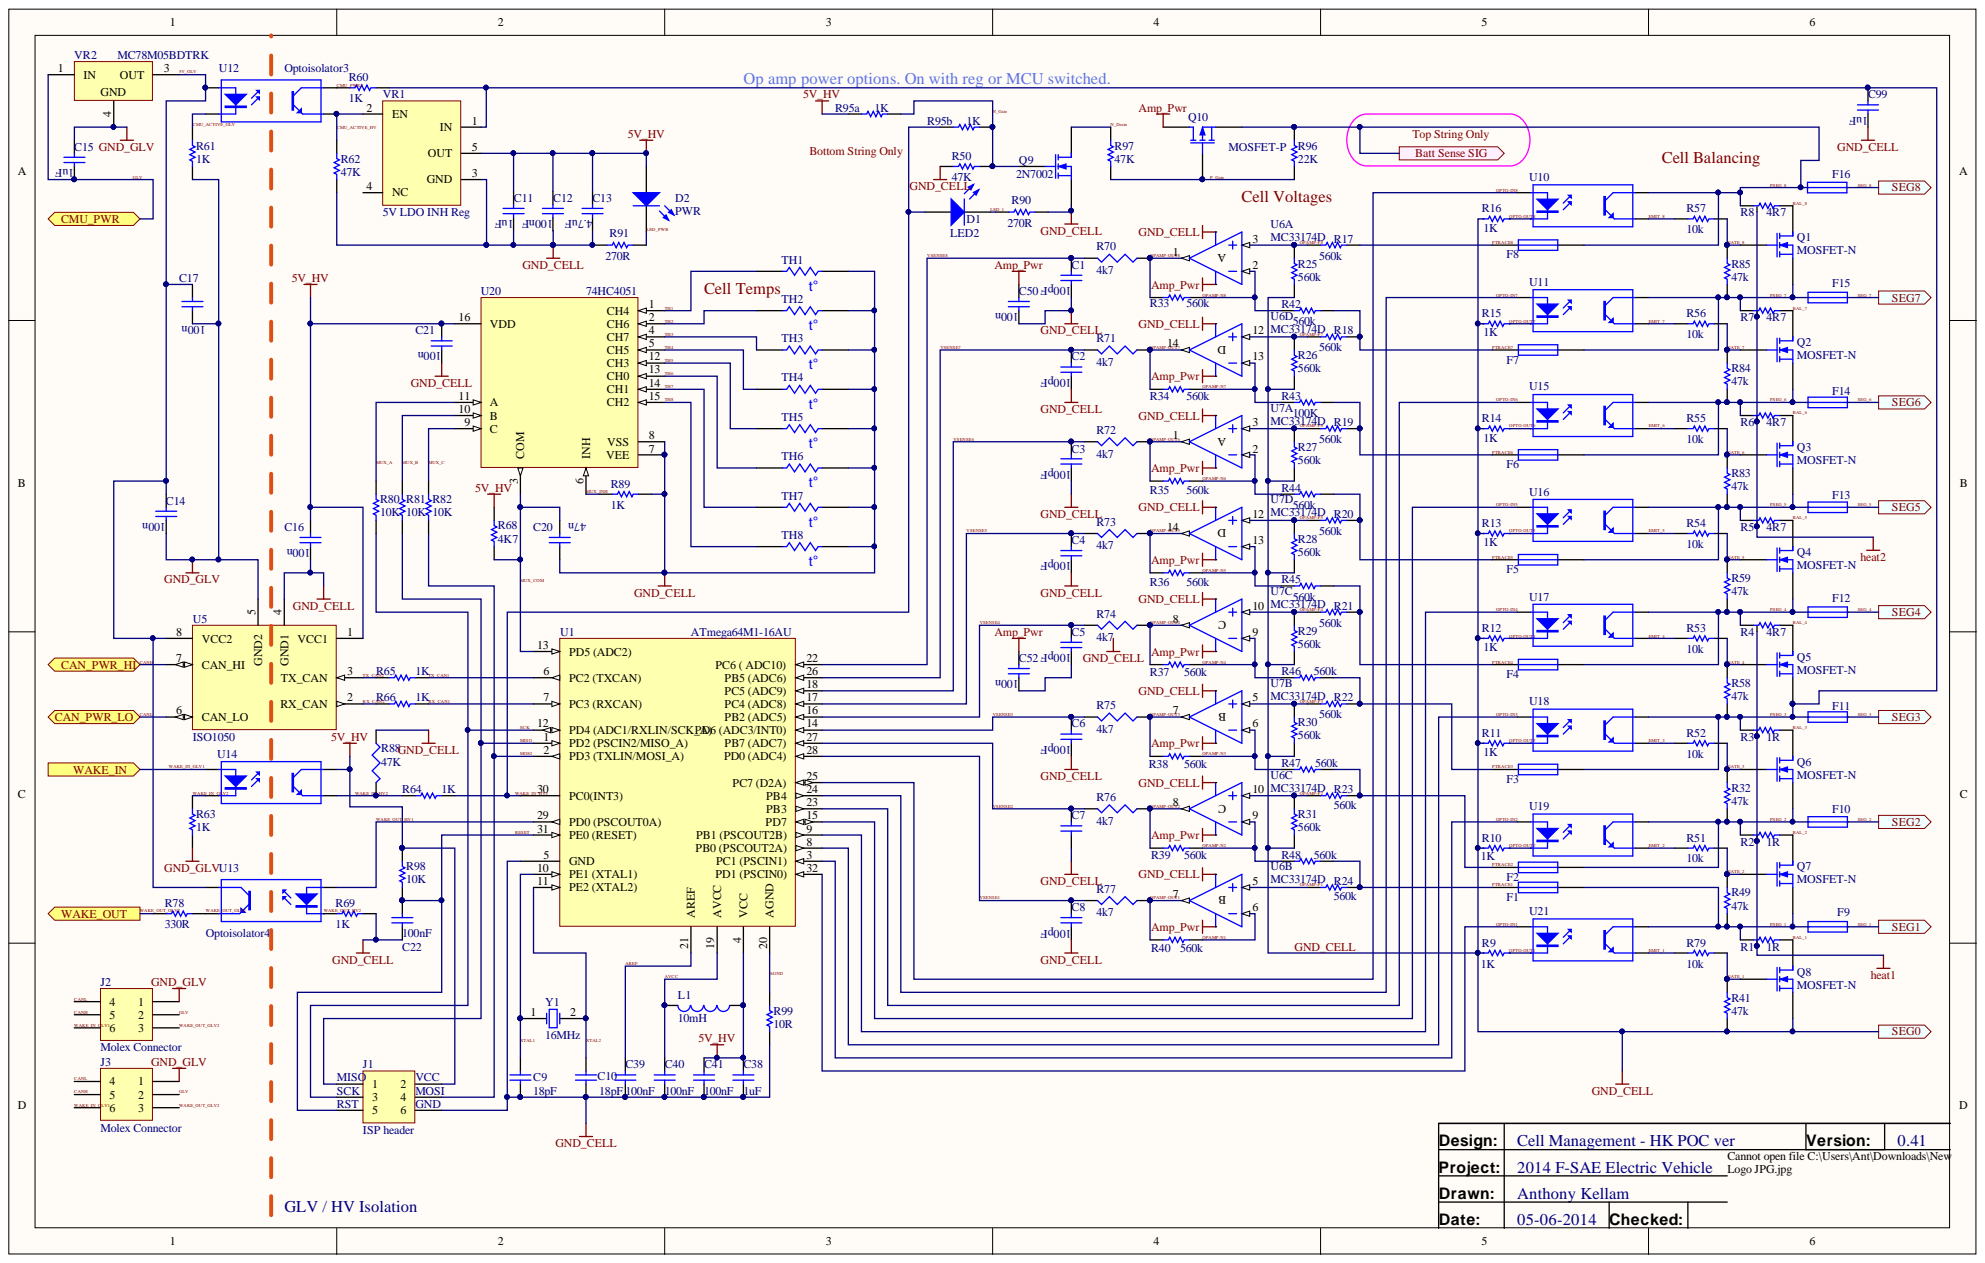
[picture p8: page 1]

Op amp power options. On with reg or MCU switched.

Design: | Cell Management - HK POC ver | Version: | 0.41
Project: | Cannot open file C:\Users\Ant\Downloads\New 2014 F-SAE Electric Vehicle Logo JPG.jpg

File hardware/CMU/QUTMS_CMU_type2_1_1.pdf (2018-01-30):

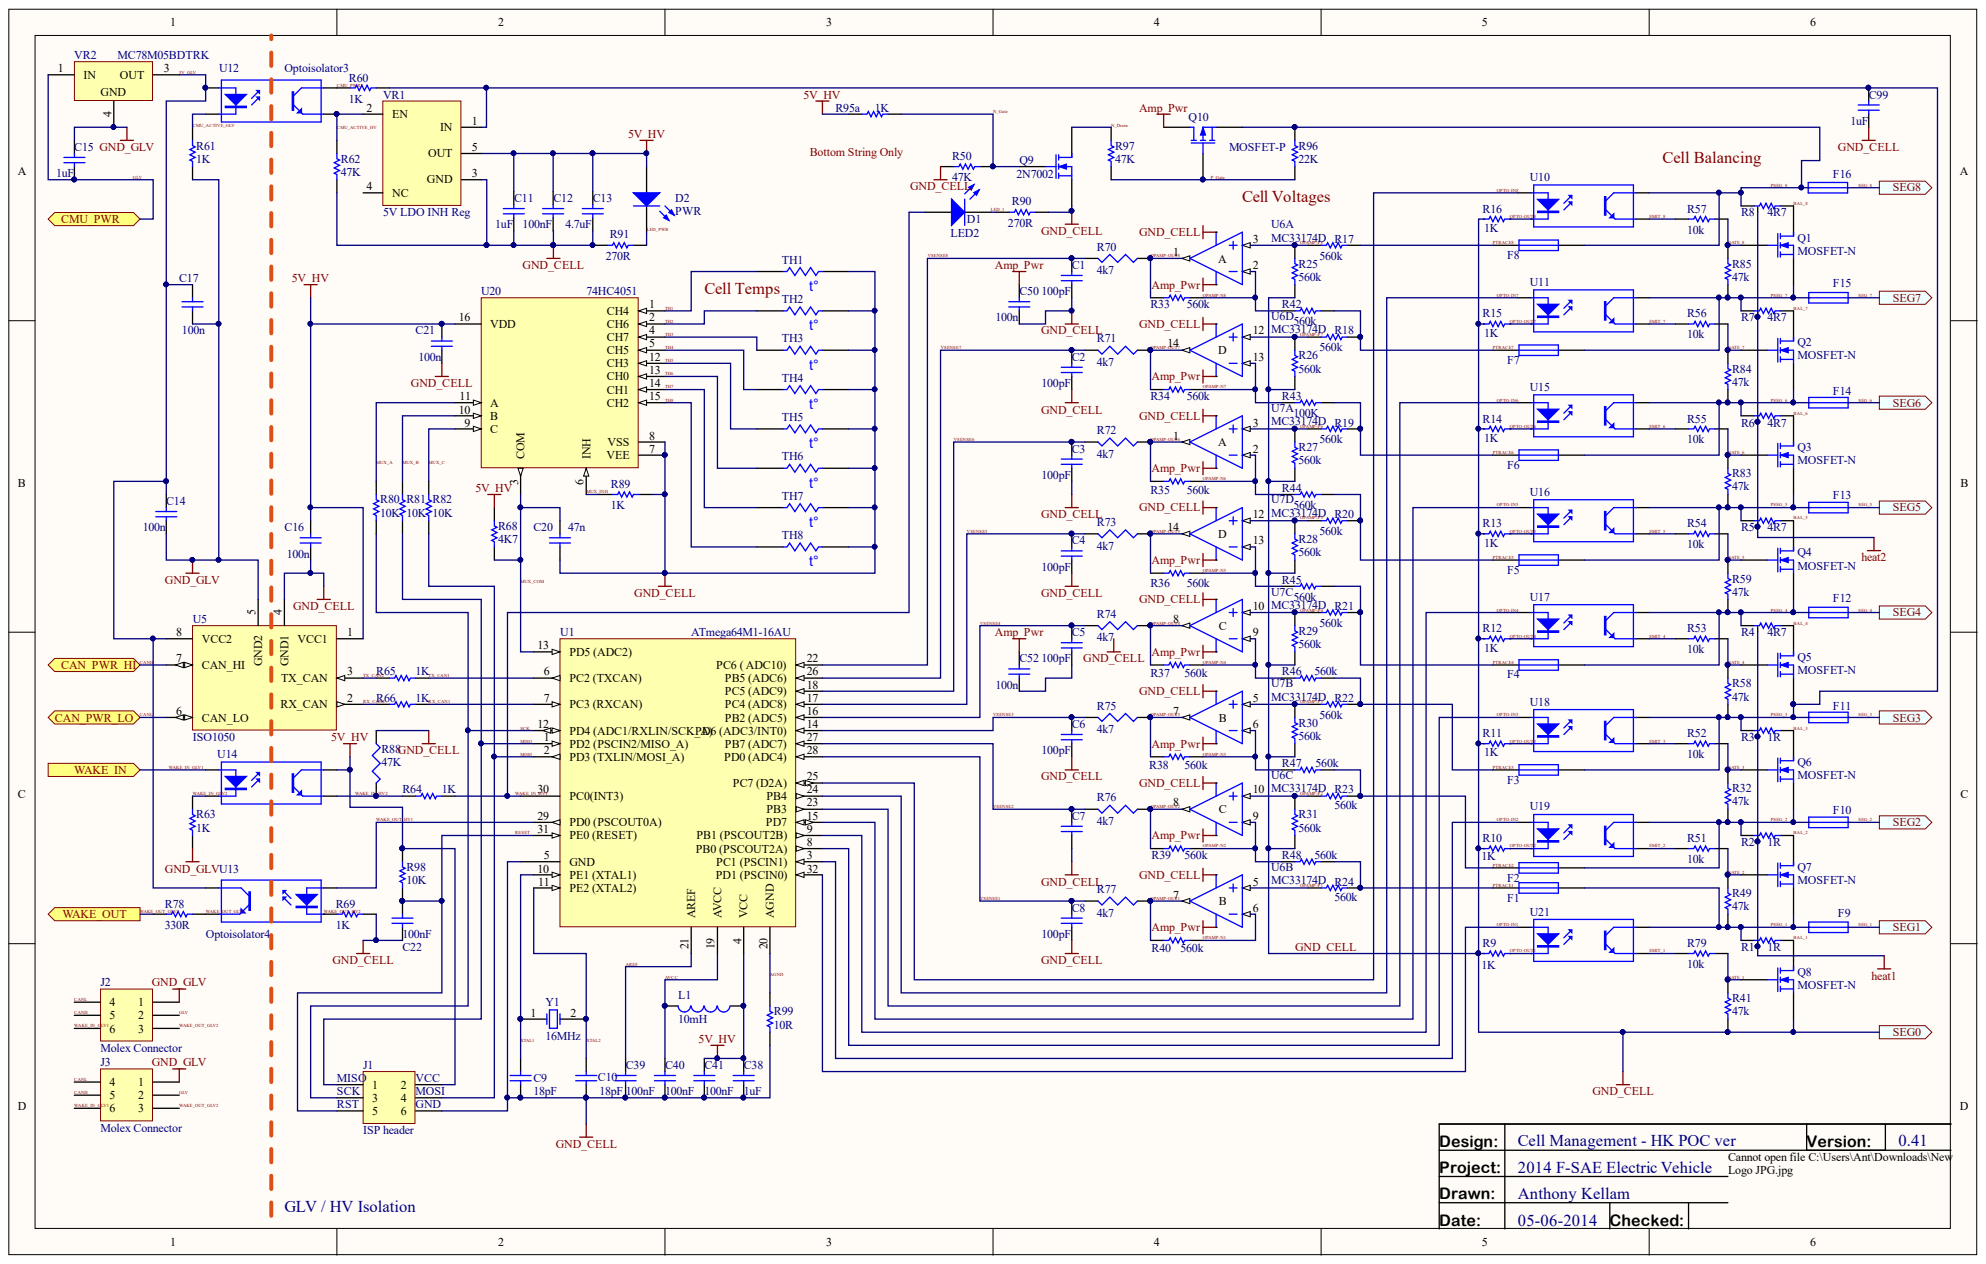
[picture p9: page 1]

Proj e ct: | Cell Management - HK POC ver Version: 05-06-2014 Ca nn ot o p e n file C:\Users\Ant\Downlo a ds\New 2 0 1 4 F-SAE Electric Vehicle Lo g o JPG.jp g
Desi gn: | | 0.4 1

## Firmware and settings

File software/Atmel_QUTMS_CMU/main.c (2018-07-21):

/*
 * Atmel_QUTMS_CMU.c
 *
 * Created: 3/07/2016 10:41:03 AM
 *  Author: julius
 */ 

#include "main.h"

void IO_init()
{

	DDRD = 0b10011111;		//7 for discharge cell 4; 2,3,4 for multiplex selector; 0 for wake out, 1 for discharge cells 1 and 2; 6 is ADC input; 5 is ADC input.
	DDRC = 0b10000110;		//7 and 1 for cell balancing; 6,5 and 4 for ADC in; 3 for CAN Rx; 2 for CAN Tx; 0 for wake in (doesn't matter).
	DDRB = 0b00011011;		//7, 6, 5 and 2 for ADC in; 4, 3, 1 and 0 for cell balance.
	
	EICRA = (1<<ISC31)|(1<<ISC30);	//0b11000000	//to enable rising edge of INT3 on PINC0 to cause an external interrupt
	EIMSK = (1<<INT3);				//this may not be legal, the data sheet said it was read only, otherwise it might be 1<<INT1 and 1<<INT0 to represent 3 (0b00000011)
	//EIFR bits INTF3..0 hold information on whether the interrupt has occurred.
	//PCICR is useful when using the level change is being used to indicate the interrupt. hi-low or low-hi maybe
	sei();
}

void Parameters_init()
{
	deviceID  = CMU_eeprom_read(EEPROM_DEVICE_ID);
	ADC_SAMPLES  = CMU_eeprom_read(EEPROM_ADC_SAMPLES);
	fw_version = CMU_eeprom_read(EEPROM_FW_VERSION);
	CELL_V_DIFF_MAX_THRESHOLD = CMU_eeprom_read(EEPROM_CELL_V_DIFF_MAX_THRESHOLD);
	CELL_V_DIFF_MIN_THRESHOLD = CMU_eeprom_read(EEPROM_CELL_V_DIFF_MIN_THRESHOLD);
	DISCHARGE_SCALE = CMU_eeprom_read(EEPROM_DISCHARGE_SCALE);
	EEPROMWriteComplete = 0;
}

void ADC_init()
{
	ADMUX=(1<<REFS0)|(1<<AREFEN);                      // For Aref=AVcc with external capacitor;
	ADMUX &= ~(1<<ADLAR);								//make sure adlar is not set.
	ADCSRA=(1<<ADEN)|(1<<ADPS2)|(1<<ADPS1)|(1<<ADPS0); //Prescaler div factor = 128, 125kHz --> lowest we can go for best accuracy.
}

void Cells_init(cell * _cells)
{
	uint8_t cell_temp_config[] = {7,6,3,2,5,4,1,0};		//multiplexer number to use for each different cell.
	uint8_t cell_discharge_config[8] = {PIND1,PINC1,PINB0,PINB1,PIND7,PINB3,PINB4,PIND0};
	//uint8_t cell_vLevel_config[8] = {10,9,8,7,6,5,4,2};	//ADC Channels to use	
	uint8_t cell_vLevel_config[8] = {4,7,3,5,8,9,6,10};	//ADC Channels to use
		
	
	for(uint8_t cParse = 0; cParse <=7; cParse++)
	{
		_cells[cParse].cell_num = cParse;								//assign our cell objects a local identifier number
		_cells[cParse].temp_channel	= cell_temp_config[cParse];			//assign cell object the multiplexer value it needs to set before reading ADC value
		_cells[cParse].voltage_channel = cell_vLevel_config[cParse];		//assign cell ADC channel to use when reading
		_cells[cParse].discharge_pin = cell_discharge_config[cParse];	//assign which pin to use to discharge
	}
}

uint16_t CMU_eeprom_read(uint16_t address)
{
	while(!eeprom_is_ready());
	return eeprom_read_word((const uint16_t *)address);
}

void CMU_eeprom_write(uint16_t address, uint16_t value)
{
	while(!eeprom_is_ready());
	eeprom_write_word((uint16_t *)address, value);
}

uint16_t ADC_read(uint8_t channel)
{
	channel = (ADMUX & 0xe0)|(channel & 0x1F); //ADMUX | 0b11100000 and channel | 0b00011111 --> this keeps all bits of ADMUX the same except for the bits signalling which channel to use.
	ADMUX = channel;
	ADCSRA |= (1<<ADSC);							//ADSC (single conversion bit) is set to 1 to start the conversion process.
	while(!(ADCSRA & (1<<ADIF)));				//run a loop while the conversion is taking place.
	uint16_t result = 0;
	result = ADCL;								//read ADCL first, ADCH after --> order is important! --> also not sure if this code is correct. other ADC examples return 'ADC' instead.
	result |= ((3 & ADCH) << 8);
	ADCSRA|=(1<<ADIF);							//once read and done, clear the 'complete' status by writing 1 to the ADIF bit.
	return result;								//pass the 10 bit ADC number to requesting function.
}

void LED_flash(uint8_t duration)
{
	duration = duration/2;
	DDRC |= 1<<PINC0;
	PORTC |= 1<<PINC0;
	for(uint8_t i = 0; i < duration; i++)
	{
		_delay_us(995);
	}
	PORTC &= ~(1<<PINC0);
	DDRC &= ~(1<<PINC0);
	for(uint8_t i = 0; i < duration; i++)
	{
		_delay_us(995);
	}
}
void LED_on()
{
	DDRC |= 1<<PINC0;
	PORTC |= 1<<PINC0;
}
void LED_off()
{
	PORTC &= ~(1<<PINC0);
	DDRC &= ~(1<<PINC0);
}

uint16_t Convert_ADCtoMilliVolts(uint16_t ADCValue)
{
    //return as invalid;
	if(ADCValue >= 1023) return  65535;
    //finish the conversion with error if the value will be completely unreasonable.
	if(ADCValue <  20 ) return 65535;
    //xxxxx.xxxxf results in the calculated value being a float, instead of an integer
	return (uint16_t)(((double)ADCValue*0.000977517f)*RAIL_V-MV_OFFSET);

}

uint16_t Read_voltage(cell * _cell)
{
	uint32_t sum = 0;
	for(uint8_t c = 0; c < AVG_V_SIZE; c++)
	{
		//elementToUpdate = (rand() % AVG_V_SIZE);						//choose a random element to update
		sum += Convert_ADCtoMilliVolts(ADC_read(_cell->voltage_channel));			//read the voltage
		//if(elementToUpdate < AVG_V_SIZE)_cell->voltages[elementToUpdate] = tempVoltage;	//if the random number is valid, set the chosen element to the new voltage.
	}
	return (uint16_t)(sum/AVG_V_SIZE);	//return the average.
}

void Read_all_voltages(cell * _cells)
{

	cell * t_cells = _cells;
	for(uint8_t cellCount = 0; cellCount <= 7; cellCount++)
	{
		t_cells = _cells+cellCount;
		t_cells->voltage = Read_voltage(t_cells);	//move through all cells and assign voltage levels.
	}

}

uint8_t TX_cellVoltage(cell *_cells)
{
	int8_t mob;
	uint8_t tempData[8];
	
	for(uint8_t cellCount = 0; cellCount <= 3; cellCount++)
	{
		tempData[cellCount*2]	= _cells[cellCount].voltage >> 8;
		tempData[cellCount*2+1] = _cells[cellCount].voltage;
	}
	mob = CAN_findFreeTXMOB();
	if(mob>=0)CAN_TXMOB(mob, 8, tempData, ((uint32_t)deviceID<<18)|((uint32_t)AMUID<<8)|VOLT1_ID, 0); //transmit first 4 cell data and do not wait for finish
	else return 0;
	_delay_ms(5);
	
	for(uint8_t cellCount = 4; cellCount <= 7; cellCount++)
	{
		tempData[(cellCount-4)*2]	= _cells[cellCount].voltage >> 8;
		tempData[(cellCount-4)*2+1] = _cells[cellCount].voltage;
	}
	mob = CAN_findFreeTXMOB();
	if(mob>=0)CAN_TXMOB(mob, 8, tempData, ((uint32_t)deviceID<<18)|((uint32_t)AMUID<<8)|VOLT2_ID, 0); //transmit first 4 cell data and do not wait for finish
	else return 0;
	_delay_ms(5);
	
	return 1;
}


uint16_t Convert_ADCtoCelsius(uint16_t ADCValue)		//will spit out a value from 0 to 140  (ADC 10 bit value 1023 will be 255, lower than 187 will be 255)
{
	if(ADCValue >= 1023)return 255;				//this indicates the sensor has failed, perhaps a short somewhere?
	if(ADCValue < 187 )return 255;				//finish the conversion with error if the value will be invalid.
	uint8_t i = 0;
	while(TEMP_Celsius_pos[i] > ADCValue) i++;	//move through the array until values position is found. C will be equal to elements of the array we went through.
	return i;
}

uint16_t Read_temp(cell * _cell)
{


	uint32_t sum = 0;
	PORTD = (PORTD & 0xe3)|((_cell->temp_channel<<2) & 0x1c);		//so as to not change the rest of PORTD, we 'AND' the values of PORTD and uiMX with a mask
	for(uint8_t c = 0; c < ADC_SAMPLES; c++)
	{
		//elementToUpdate = (rand() % AVG_V_SIZE);						//choose a random element to update
		sum += Convert_ADCtoCelsius(ADC_read(TEMP_MULTIPLEX_CH));			//read the voltage
		//if(elementToUpdate < AVG_V_SIZE)_cell->voltages[elementToUpdate] = tempVoltage;	//if the random number is valid, set the chosen element to the new voltage.
	}
	return (uint16_t)(sum/AVG_V_SIZE);	//return the average.
	
	/*
	uint16_t tempTemp[ADC_SAMPLES-1];
	uint8_t count = 0;
	uint16_t sum = 0, avgTemp = 0;
	PORTD = (PORTD & 0xe3)|((_cell.temp_channel & 0x1c)<<2);		//so as to not change the rest of PORTD, we 'AND' the values of PORTD and uiMX with a mask
	for(uint8_t i = 0; i < ADC_SAMPLES; i++)
	{
		tempTemp[i] = Convert_ADCtoCelsius(ADC_read(TEMP_MULTIPLEX_CH));	//retrieve ADC reading from our channel, and convert to celsius.
		if (tempTemp[i] != 255)
		{
			sum+= tempTemp[i];		//add the temp to the sum if it's valid
			count++;				//increment the counter of valid values.
		}
	}
	avgTemp = sum/count;
	if(!count)return 255;			//if there were no valid values, return error value;
	else return avgTemp;			//otherwise return the average of the ADC_SAMPLES taken
	*/
}

void Read_all_temps(cell *_cells)
{
	cell * t_cells = _cells;
	for (uint8_t cellCount = 0; cellCount <= 7; cellCount++)
	{
		t_cells = _cells+cellCount;									//our address must increment to modify/use the next value in the cell array
		t_cells->temperature = Read_temp(t_cells);		//move through all the cells and assign temperatures.
	}
}

uint8_t TX_cellTemps(cell *_cells)
{
	int8_t mob;
	uint8_t tempData[8];
	
	for(uint8_t cellCount = 0; cellCount <= 3; cellCount++)
	{
		tempData[cellCount*2]	= _cells[cellCount].temperature >> 8;
		tempData[cellCount*2+1] = _cells[cellCount].temperature;
	}
	mob = CAN_findFreeTXMOB();
	if(mob>=0)CAN_TXMOB(mob, 8, tempData, ((uint32_t)deviceID<<18)|((uint32_t)AMUID<<8)|TEMP1_ID, 0); //transmit first 4 cell data and do not wait for finish
	else return 0;
	_delay_ms(5);
	for(uint8_t cellCount = 4; cellCount <= 7; cellCount++)
	{
		tempData[(cellCount-4)*2]	= _cells[cellCount].temperature >> 8;
		tempData[(cellCount-4)*2+1] = _cells[cellCount].temperature;
	}
	mob = CAN_findFreeTXMOB();
	if(mob>=0)CAN_TXMOB(mob, 8, tempData, ((uint32_t)deviceID<<18)|((uint32_t)AMUID<<8)|TEMP2_ID, 0); //transmit first 4 cell data and do not wait for finish
	else return 0;
	_delay_ms(5);
	return 1;
}

void Discharge_cells(cell high_1, cell high_2, cell high_3, cell lowest)					//parameters: cell to reduce; pin that the cell discharge circuit is located on; duration of discharge in seconds.
{

	uint16_t duration_high_1 = (high_1.voltage - lowest.voltage)*DISCHARGE_SCALE;			//sets the duration the highest should discharge for. Dependant on the difference between it and the lowest cell voltage
	uint16_t duration_high_2 = (high_1.voltage - lowest.voltage)*DISCHARGE_SCALE;			//sets the duration the second highest should discharge for. Dependant on the difference between it and the lowest cell voltage
	uint16_t duration_high_3 = (high_1.voltage - lowest.voltage)*DISCHARGE_SCALE;			//sets the duration the third highest should discharge for. Dependant on the difference between it and the lowest cell voltage

	uint8_t _cells = ( CellNum[high_1.cell_num] | CellNum[high_2.cell_num] | CellNum[high_3.cell_num]);			//create a byte, with bits of 1 indicating which cells are to be discharged. e.g 0b10010001 would be cell 0, cell 4 and cell 7 are the highest cells, therefore will be discharged, based upon the difference between it and the highest.
	int8_t mob = CAN_findFreeTXMOB();
	CAN_TXMOB(mob, 1, &_cells, ((uint32_t)deviceID<<18)|((uint32_t)AMUID<<8)|15, 0); //transmit cells to be discharged and do not wait for finish
	
	
	/*for(uint16_t count = 0; count < duration_high_1; count++)
	{
		PORTB |= ((_cells&CELL7)>>7)|((_cells&CELL6)>>5)|((_cells&CELL5)>>2)|(_cells&CELL4);					//turn on discharge for cells 7..4, if they are specified in _cells
		PORTC |= (((_cells&CELL3)<<4)|((_cells&CELL0)<<1));														//turn on discharge for cells 3 and 0, if their corresponding bits are specified in _cells
		PORTD |= ((_cells&CELL1)>>1|(_cells&CELL2)>>1);															//turn on discharge for cells 2 and 1, if their corresponding bits are on in _cells

		_delay_us(1);				//~50% duty cycle, ~2us pulse width.

		PORTB &= ~(((_cells&CELL7)>>7)|((_cells&CELL6)>>5)|((_cells&CELL5)>>2)|(_cells&CELL4));					//turn the discharge off.
		PORTC &= ~(((_cells&CELL3)<<4)|((_cells&CELL0)<<1));
		PORTD &= ~(((_cells&CELL1)>>1|(_cells&CELL2)>>1));

		if(count >= duration_high_3 && (_cells & CellNum[high_3.cell_num])) _cells &= ~(CellNum[high_3.cell_num]);		//when the counter reaches the duration of the high_2 and high_3, we will remove the corresponding bit in _cells, so that it does not discharge them anymore
		if(count >= duration_high_2 && (_cells & CellNum[high_2.cell_num])) _cells &= ~(CellNum[high_2.cell_num]);

	}*/
}

void Balance_on()
{
	TCCR0A = 0;
	TCCR0B = (1<<CS01);
	//TCNT0 = 0;
	OCR0A = 200;
	TIMSK0 = (1<<OCIE0A);
	
}

void Balance_off()
{
	//TCCR0B = 0;
	TIMSK0 = 0;
	PORTB &= ~((CELL2>>2)|(CELL3>>2)|(CELL5>>2)|(CELL6>>2)); //turn off discharge for cells 7..4, if they are specified in _cellsToBalance
	PORTC &= ~((CELL1)|(CELL7)); //turn off discharge for cells 3 and 0, if their corresponding bits are specified in _cellsToBalance
	PORTD &= ~((CELL0<<1)|(CELL4<<3)); //turn off discharge for cells 2 and 1, if their corresponding bits are on in _cellsToBalance
	LED_off();
}
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
int main(void)
{
	_delay_ms(10);
	
	
	CMU_eeprom_write(EEPROM_DEVICE_ID, 6);
	CMU_eeprom_write(EEPROM_ADC_SAMPLES, 3);
	CMU_eeprom_write(EEPROM_FW_VERSION, 1003);
	CMU_eeprom_write(EEPROM_CELL_V_DIFF_MAX_THRESHOLD, 500);
	CMU_eeprom_write(EEPROM_CELL_V_DIFF_MIN_THRESHOLD, 500);
	CMU_eeprom_write(EEPROM_DISCHARGE_SCALE, 200);
	
	EEPROMWriteComplete = 0;
	
	IO_init();		//initialise IO and INT3 for waking up from power down mode
	//Wake_Set();
	ADC_init();		//initialises ADC
	CAN_init();		//initialises CAN, without enabling any receive MOBs
	CAN_RXInit(4, 0, 0, 0);	//set mob up for listening to audit requests
	
	//srand(ADC_read(0));
	Parameters_init();	//disable this until we have the parameters on the eeprom
	PowerDown();		//shutdown until woken for the first time
	_delay_ms(200);	//await registration messages which will be automatically handled in interrupts
	
	if(!registered)_delay_ms(800);
	if (WAKE_IN_PIN && !registered) //if the wake in pin is still high and we aren't registered, there is a problem
	{
		while(1)					//loop endlessly
		{
			LED_flash(50);			//flashing LED 3 times
			LED_flash(50);
			LED_flash(50);
			_delay_ms(2000);		//every two seconds.
			
		}	
	}
	
	CAN_RXInit(5, 0, ADMINmsk, ADMIN );				//set mob up for listening to admin messages
	cell cells[8];					//create primary cell array. this will hold all configuration and collected data on the cells.
    Cells_init(cells);
	CellBalanceMode = 0;
	//uint16_t x = 0;
	//double temp = 0.00;
	Wake_Set();
	while(WAKE_IN_PIN);
	Wake_Unset();
	PowerDown();
	
	while(1)
    {
		//mob = CAN_findFreeTXMOB();
		//if(mob>=0)CAN_TXMOB(mob, 0, 0, ((uint32_t)deviceID<<18)|((uint32_t)AMUID<<8)|AUDIT_RESPONSE, 0); //transmit registration and do not wait for finish
		//
		LED_on();
		_delay_ms(5);		//after powering up again, wait for voltages to settle
		//PORTD = (PORTD & 0xe3)|((cells[3].temp_channel<<2) & 0x1c);
		//x = ADC_read(TEMP_MULTIPLEX_CH);
		//x = 279;
		
		//temp = 0.0000004*pow(x,3) -0.006*pow(x,2) +0.3424*x -37.7329;
		
		
		
		CellBalanceMode = 0;		//after one balance process, ensure that balancing is turned off. this is to ensure that if no contact is received from the AMU, things won't blow up

		Balance_off();
		Read_all_voltages(cells);	//Reads all voltages, 3.7ms
		if(!(TX_cellVoltage(cells)))LED_flash(20); 
		Read_all_temps(cells);
		//cells[3].temperature = (uint16_t)temp;
		
		if(!(TX_cellTemps(cells)))LED_flash(20);
		//_delay_ms(10);
		Wake_Set();
			
		
		if(CellBalanceMode)
		{
			LED_off();
			Balance_init(cells);
			Balance_on();
			LED_flash(50);
		}
		
		if(!(WAKE_IN_PIN))
		{
			LED_off();
			_delay_ms(1);
			Wake_Unset();
			PowerDown();
			//LED_on();
		}
		else
		{
			_delay_ms(200);
			CANPAGE = (4 << 4);
			CANSTMOB &= ~(1 << RXOK);	//unset the RXOK bit to clear the interrupt.
		}
		CANPAGE = (4 << 4);
		CANSTMOB &= ~(1 << RXOK);	//unset the RXOK bit to clear the interrupt.
		CAN_RXInit(4,0,AMUmsk, AMU);	//set mob up for listening to the AMU
		//while(CellBalanceCounter < BALANCE_DUTY_CYCLE);
		//Balance_cells(cells);
		//Read_all_temps(cells);		//Reads all temperatures, 2.9ms

		
		//PORTD |= (1<<PIND7);		//send wake out, halfway through sending our data back to the AMU.
    }
}

ISR(INT3_vect)
{
	SMCR = (0<<SM2)|(0<<SM1)|(1<<SM0)|(0<<SE);		//disable the mode, and disable the enable bit.
}

ISR(CAN_INT_vect)
{
	//uint8_t authority;
	int8_t mob;	
	
	if((CANSIT2 & (1 << SIT4)))	//we received a CAN message on mob 5, which is set up to receive exclusively from the AMU.
	{
		
		CANPAGE = (4 << 4);			//set the canpage to the receiver MOB
		if((CANIDT4 >> 3) == AUDIT_REQUEST && !registered )	//if the received ID has packet type audit request, and we are not already registered, we will send a registration request.
		{
			mob = CAN_findFreeTXMOB();
			AMUID =  ((CANIDT2 >> 5) & 0b00000111);	//last 5 bits of CANIDT3 contain the lower 5 bits of the sender ID
			AMUID |= ((CANIDT1 << 3) & 0b11111000);	//first 3 bits of CANIDT2 contain the last 3 bits of the sender ID
			uint8_t data[2] = {(fw_version>>8) & 0xFF, fw_version & 0xFF};
			if(mob>=0)CAN_TXMOB(mob, 2, data, ((uint32_t)deviceID<<18)|((uint32_t)AMUID<<8)|AUDIT_RESPONSE, 0); //transmit registration and do not wait for finish	
			
		}
		else if((CANIDT4 >> 3)== READ_RECEIPT && !registered )
		{
			Wake_Set();
			registered = 1;
		}
		else if((CANIDT4 >> 3)== BALANCE_ON && (CANCDMOB & 0b1111) == BALANCE_NPACKETS)
		{
			//this packet processing is important, so we need to do it in here.
			for(uint8_t i = 0; i < BALANCE_NPACKETS; i++)
			{
				switch(i)
				{
					case 0:
						BALANCE_TARGET_VOLTAGE = (uint16_t)(CANMSG<<8);		//CAN byte 1
						break;
					case 1:
						BALANCE_TARGET_VOLTAGE |= CANMSG;					//CAN byte 2
						break;
					case 2:
						BALANCE_DUTY_CYCLE = CANMSG;						//CAN byte 3
						break;
					case 3:
						BALANCE_RESERVED1 = CANMSG;							//CAN byte 4
						break;
					case 4:
						BALANCE_RESERVED2 = CANMSG;							//CAN byte 5
						break;
					default:
						break;
				}
			}
			if(BALANCE_TARGET_VOLTAGE > 3200 && BALANCE_TARGET_VOLTAGE < 4200 && BALANCE_DUTY_CYCLE < 50) CellBalanceMode = 1;		//only if the packets we have received are valid, will we turn balancing on
		}
		else if((CANIDT4 >> 3)== BALANCE_OFF )
		{
			CellBalanceMode = 0;
		}
		CAN_RXInit(4,0,AMUmsk, AMU);	//set mob up for listening to the AMU
	}
	CANPAGE = (4 << 4);
	CANSTMOB &= ~(1 << RXOK);	//unset the RXOK bit to clear the interrupt.
	LED_off();
}

ISR(TIMER0_COMPA_vect)
{
	CellBalanceCounter++;
	if(CellBalanceCounter<BALANCE_DUTY_CYCLE)	//for the beginning of the duty cycle, turn cell balancing on.
	{
		LED_on();
		PORTB |= (((_cellsToBalance&CELL2)>>2)|((_cellsToBalance&CELL3)>>2)|((_cellsToBalance&CELL5)>>2)|((_cellsToBalance&CELL6)>>2));					//turn on discharge for cells 7..4, if they are specified in _cellsToBalance
		PORTC |= (_cellsToBalance&CELL1)|(_cellsToBalance&CELL7);														//turn on discharge for cells 3 and 0, if their corresponding bits are specified in _cellsToBalance
		PORTD |= ((_cellsToBalance&CELL0)<<1)|((_cellsToBalance&CELL4)<<3);									//turn on discharge for cells 2 and 1, if their corresponding bits are on in _cellsToBalance
	}
	else			//otherwise, turn the cell balancing off.
	{
		PORTB &= ~((CELL2>>2)|(CELL3>>2)|(CELL5>>2)|(CELL6>>2));					//turn off discharge for cells 7..4, if they are specified in _cellsToBalance
		PORTC &= ~((CELL1)|(CELL7));														//turn off discharge for cells 3 and 0, if their corresponding bits are specified in _cellsToBalance
		PORTD &= ~((CELL0<<1)|(CELL4<<3));									//turn off discharge for cells 2 and 1, if their corresponding bits are on in _cellsToBalance
		LED_off();
	}
	if(CellBalanceCounter >= 100)CellBalanceCounter = 0;
}

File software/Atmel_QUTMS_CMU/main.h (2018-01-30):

/*
 * Atmel_QUTMS_CMU.h
 *
 * Created: 3/07/2016 10:44:46 AM
 *  Author: julius
 */ 


#ifndef QUTMS_CMU_H_
#define QUTMS_CMU_H_

#define F_CPU 		16000000UL
#define DEVICE_ID 	0x03
#include "AtmelCAN.h"
#include <util/delay.h>
#include <avr/io.h>
#include <avr/pgmspace.h>
#include <avr/sleep.h>
#include <avr/interrupt.h>
#include <avr/eeprom.h>
#include <stdlib.h>
#include <math.h>

#define RAIL_V 5000
#define AVG_V_SIZE 5
//#define BALANCE_DUTY_CYCLE 90
#define MV_OFFSET 62
#define TEMP_MULTIPLEX_PORT PORTD	//if ever the PCB design changes and the adc multiplexer changes pins, these two need to be changed
#define TEMP_MULTIPLEX_CH 2

#define WAKE_IN_PIN		PINC&(1<<PINC0)
#define VOLT1_ID 		0b00001
#define VOLT2_ID 		0b00010
#define TEMP1_ID 		0b00100
#define TEMP2_ID 		0b00101
#define STATA_ID		0b01001
#define AUDIT_REQUEST 	0b10001
#define AUDIT_RESPONSE	0b00000000000000000000000010011|(deviceID<<8)
#define AUDIT_REQmsk	0b11000000000000000000000000000
#define ADMIN		 	0b10000000000000000000000000000
#define ADMINmsk		0b10000000000000000000000000000
#define AMU				0b01000000000000000000000000000
#define AMUmsk			0b01000000000000000000000000000
#define BALANCE_NPACKETS	5



#define READ_RECEIPT 	0b10010
#define BALANCE_ON		0b10100
#define BALANCE_OFF		0b10101


#define EEPROM_DEVICE_ID					0x000
#define EEPROM_ADC_SAMPLES					0x002

#define EEPROM_FW_VERSION					0x004
#define EEPROM_CELL_PARAMETERS				0x040
#define EEPROM_CELL_V_DIFF_MAX_THRESHOLD	0x040
#define EEPROM_CELL_V_DIFF_MIN_THRESHOLD	0x042
#define EEPROM_CELL_V_ERR_MAX				0x044
#define EEPROM_CELL_V_ERR_MIN				0x046
#define EEPROM_DISCHARGE_SCALE				0x048

#define CELL0			1
#define CELL1			2
#define CELL2			4
#define CELL3			8
#define CELL4			16
#define CELL5			32
#define CELL6			64
#define CELL7			128

#define _cellsToBalance GPIOR0

const int TEMP_Celsius_pos[141] =  // Positive Celsius temperatures (ADC-value)
{                           			// from 0 to 140 degrees
	938, 935, 932, 929, 926, 923, 920, 916, 913, 909, 906, 902, 898,
	894, 891, 887, 882, 878, 874, 870, 865, 861, 856, 851, 847, 842,
	837, 832, 827, 822, 816, 811, 806, 800, 795, 789, 783, 778, 772,
	766, 760, 754, 748, 742, 735, 729, 723, 716, 710, 703, 697, 690,
	684, 677, 670, 663, 657, 650, 643, 636, 629, 622, 616, 609, 602,
	595, 588, 581, 574, 567, 560, 553, 546, 539, 533, 526, 519, 512,
	505, 498, 492, 485, 478, 472, 465, 459, 452, 446, 439, 433, 426,
	420, 414, 408, 402, 396, 390, 384, 378, 372, 366, 360, 355, 349,
	344, 338, 333, 327, 322, 317, 312, 307, 302, 297, 292, 287, 282,
	277, 273, 268, 264, 259, 255, 251, 246, 242, 238, 234, 230, 226,
	222, 219, 215, 211, 207, 204, 200, 197, 194, 190, 1
};


typedef struct cell
{
	uint8_t temp_channel, voltage_channel, discharge_pin, cell_num;
	uint16_t temperature, voltage;
	uint16_t voltages[AVG_V_SIZE];
}cell;

//live changeable parameters
uint16_t ADC_SAMPLES = 10;					//3 samples will be taken of the ADC 10 bit values, before the variable is stored.
uint8_t DISCHARGE_DURATION = 5;				//in seconds, how long the cell will dissipate power for, per discharge. DISCHARGE_MODE specifies how many discharges are to take place. HEAVY MODE AT 5 seconds would be 25 seconds per CMU to balance cells
uint16_t CELL_V_DIFF_MAX_THRESHOLD = 500;	//differences greater than 500mV will stop the balancing process.
uint16_t CELL_V_DIFF_MIN_THRESHOLD = 10;	//ignore differences between voltages of +- 10mV
uint16_t CELL_V_ERR_MIN = 2900;
uint16_t CELL_V_ERR_MAX = 4500;
uint16_t DISCHARGE_SCALE = 200;				//scale of discharge. works in us per mV of difference
uint8_t registered = 0;
uint8_t EEPROMWriteComplete = 0;
uint8_t CellBalanceMode = 0;
uint16_t deviceID = 0x05;
uint16_t fw_version = 0;
uint8_t AMUID = 0xFF;
//volatile uint8_t _cellsToBalance = 0;
volatile uint8_t CellBalanceCounter = 0;
volatile uint8_t CellNum[8] = {1, 2, 4, 8, 16, 32, 64, 128};
volatile uint8_t BALANCE_DUTY_CYCLE = 20;
uint16_t BALANCE_TARGET_VOLTAGE = 3700;
uint8_t BALANCE_RESERVED1 = 0x00;
uint8_t BALANCE_RESERVED2 = 0x00;

//void *NULL;
void Discharge_cells(cell high_1, cell high_2, cell high_3, cell lowest);
void LED_flash(uint8_t duration);

uint16_t CMU_eeprom_read(uint16_t address);
void CMU_eeprom_write(uint16_t address, uint16_t value);



#endif /* QUTMS_CMU_H_ */

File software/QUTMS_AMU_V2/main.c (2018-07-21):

/*
 * QUT_AMU_1.c
 *
 *  Created on: 25 Apr 2015
 *      Author: julius
 */

#include "main.h"

uint16_t AMU_eeprom_read(uint16_t address)
{
	while(!eeprom_is_ready());
	return eeprom_read_word((const uint16_t *)address);
}

void AMU_eeprom_write(uint16_t address, uint16_t value)
{
	while(!eeprom_is_ready());
	eeprom_write_word((uint16_t *)address, value);
}

void Parameters_init()
{
	deviceID  = AMU_eeprom_read(EEPROM_DEVICE_ID);
	fw_version = AMU_eeprom_read(EEPROM_FW_VERSION);
}

void PCINT_init() //Needed for detecting interrupts from the MCP2515
{
	PCICR = (1<<PCIE0);			//enable from pin 26 to pin 16
	MCP2515_reg_write(MCP2515_CANINTF, 0b00000000);
	PCMSK0 = (1<<PCINT4)|(1<<PCINT3);
	
}

/**
 * Function: init_cmuData
 * Will fill in the blank cmu struct array with zeros
 */
void init_cmuData(CMU * cmu)
{
	for(uint8_t count = 0; count < CMU_COUNT; count++)
	{
		cmu->CMU_num = 0;
		cmu->CMU_ID = 0;
		for(uint8_t count2 = 0; count2 < CMU_CELL_COUNT; count2++)
		{
			cmu->temperatures[count2]=0;
			cmu->voltages[count2]=0;
		}
		cmu++;
	}
}

void IO_init()
{
	DDRB  = 0b11000110;
	DDRD  = 0b10001011;
	DDRC  = 0b10100111;
	PORTB = 0b00000000;

	PORTD |= (1<<PIND1)|(1<<PIND7)|(1<<PIND3);		//the SS pin needs to be configured as an output, otherwise we get issues on removal of the programmer.
	PORTC |= 1<<PINC7;					//set CS high
	PORTC |= (1<<MCP2515_PIN_RESET);	//set reset to high
	PORTB &= ~(1<<PINB7);		//make sure it's set up for input.
	ALARM_PORT |= (1<<ALARM_PIN);
}

void timer_init()
{
	TCCR0A = 0x00;							//normal mode.
	TCCR0B = (1<<CS02)|(0<<CS01)|(1<<CS00);	//prescale clock by 1024
	TIMSK0 = (1<<TOIE0);					//allow interrupts
}

void ADC_init()
{
	ADMUX=(1<<REFS0)|(1<<AREFEN);                      // For Aref=AVcc with external capacitor;
	ADMUX &= ~(1<<ADLAR);								//make sure adlar is not set.
	ADCSRA=(1<<ADEN)|(1<<ADPS2)|(1<<ADPS1)|(1<<ADPS0); //Prescaler div factor = 128, 125kHz --> lowest we can go for best accuracy.
}

uint16_t ADC_read(uint8_t channel)
{
	channel = (ADMUX & 0xe0)|(channel & 0x1F); //ADMUX | 0b11100000 and channel | 0b00011111 --> this keeps all bits of ADMUX the same except for the bits signalling which channel to use.
	ADMUX = channel;
	ADCSRA |= (1<<ADSC);							//ADSC (single conversion bit) is set to 1 to start the conversion process.
	while(!(ADCSRA & (1<<ADIF)));				//run a loop while the conversion is taking place.
	uint16_t result = 0;
	result = ADCL;								//read ADCL first, ADCH after --> order is important! --> also not sure if this code is correct. other ADC examples return 'ADC' instead.
	result |= ((3 & ADCH) << 8);
	ADCSRA|=(1<<ADIF);							//once read and done, clear the 'complete' status by writing 1 to the ADIF bit.
	return result;								//pass the 10 bit ADC number to requesting function.
}

uint8_t CMU_send_read_receipt(CMU * cmu)
{
	uint8_t data = 0x00; //data to send,(zeros)
	uint8_t mob = MCP2515_findFreeTxBuffer(); //obtain a free transmit buffer.
    //send a CAN packet from a free buffer, with recipient of our CMU ID, type: audit request (to now get other CMUs to talk), with 1 byte of zeros
	MCP2515_TX(mob, 0, &data, ((uint32_t)1<<27)|((uint32_t)DEVICE_ID<<18)|((uint32_t)cmu->CMU_ID<<8)|READ_RECEIPT);		
	return 1; //return successful
}

uint16_t CoulombCount_init(){
	return AMU_eeprom_read(EEPROM_COULOMB_COUNT);
}

uint16_t CoulombCount_instRead(){
	return ADC_read(ADC_HALL_EFFECT);
}

uint16_t CoulombCount_updateAndRead(uint16_t coulombCount){
	
	/* Representative of how much time the last reading was taken. */
	static uint16_t ticks;									
	uint16_t ticks_diff = globalTicks - ticks;

	/* Take a new reading of the instantaneous current, integrate, and add it to the coulomb count total */
	coulombCount += CoulombCount_instRead()*TIME_CONSTANT;

	/* Start the timer again, which is to be read the next time current is updated */
	ticks = globalTicks;
	AMU_eeprom_write(EEPROM_COULOMB_COUNT, coulombCount);
	return coulombCount;
}

/* Rough voltage to SoC representative array, voltage is in millivolts */
uint32_t voltage2SoC_Translation[100] = {100800,99744,99216,98688,98160,97920,97680,97440,97200,96960,
										  96672,96384,96096,95808,95520,95376,95232,95088,94944,94800,
										  94560,94320,94080,93840,93600,93432,93264,93096,92928,92760,
										  92592,92424,92256,92088,91920,91824,91728,91632,91536,91440,
										  91296,91152,91008,90864,90720,90672,90624,90576,90528,90480,
										  90384,90288,90192,90096,90000,89976,89952,89928,89904,89880,
										  89832,89784,89736,89688,89640,89568,89496,89424,89352,89280,
										  89232,89184,89136,89088,89040,88848,88656,88464,88272,88080,
										  87936,87792,87648,87504,87360,87168,86976,86784,86592,86400,
										  85680,84960,84240,83520,82800,80640,78480,76320,74160,72000};

uint8_t SoC_voltageTranslation(uint32_t voltage){
	uint8_t i = 0;
	
	/* Return the index once the value has been approximated. Index is analogous to percent DoD */
	while(voltage > voltage2SoC_Translation[i]){
		i++;
	}
	return 100-i;
}

uint8_t SoC_calculation(uint32_t voltage, uint16_t coulombCount, uint16_t coulombsFull){

	if(voltage < 86500 && voltage > 96000){
		uint8_t SoC = 0;
		
		/* Take the average between voltage translation and coulomb counting deterministic methods. */
		SoC = ((coulombsFull - coulombCount)/coulombsFull)*100;
		SoC = (SoC + SoC_voltageTranslation(voltage))/2;
		return SoC;
	}
	else{
		/* Return the coulomb count as the SoC. */
		return ((coulombsFull - coulombCount)/coulombsFull)*100;
	}
}
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

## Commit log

2018-01-30 Initial Content Commit
    [430450419.stp, 430450618.stp, 430450818.stp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]
2018-03-14 Added PDFs of schematics
